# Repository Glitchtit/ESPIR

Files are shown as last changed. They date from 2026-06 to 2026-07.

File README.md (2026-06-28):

# ESPIR — Zigbee IR Blaster for Home Assistant

A Home Assistant–controlled IR blaster built on the **ESP32-C6**, connected over
**Zigbee** to a **Zigbee2MQTT (Z2M)** coordinator. It **learns** IR codes from your
existing physical remotes and **replays** them on command, so HA buttons map 1:1 to
"press button → appliance fires the learned signal."

## Topology

```
[remote] --IR--> [VS1838B] --RMT RX--> MASTER (DevKitC-1, USB, Zigbee Router)
                                          |  NVS slots, custom ZCL cluster 0xFC00
                                          |  +--RMT TX--> [SZHJW] --IR--> appliance
                                          v
                       Zigbee <--> Z2M (z2m/espir.js) <--> Home Assistant
                                          |                       |
                              learn / send / read code     buttons + scripts
                                          v
        replication (HA script): copy master's learned code -> each SLAVE
                                          v
                       SLAVE (XIAO C6, LiPo, Sleepy End Device) --IR--> local appliance
```

- **Master** (ESP32-C6-DevKitC-1, USB-powered Zigbee **Router**): **learns** by raw-capturing
  from a **VS1838B** receiver and **transmits** through an **SZHJW** dual-LED module — both on
  the RMT peripheral; stores codes in NVS. Always-on, so it responds instantly and extends the
  Zigbee mesh.
- **Slave** (Seeed XIAO ESP32-C6, LiPo **Sleepy End Device**): transmit-only repeater for
  coverage in another spot, using the SZHJW dual-LED emitter (RMT). Receives learned codes
  from the master via a replication path.

> **Protocol note:** raw capture learns essentially **any** remote; NEC is auto-compacted to
> `{address, command}` for cheap storage/replication. Master and slaves share the RMT backend,
> so codes are fully interoperable.

## Why this design

A battery IR blaster that must answer HA instantly is a contradiction — Zigbee on the C6
only sips power if it sleeps deeply. The master/slave split sidesteps it: the master is
mains/USB-powered (snappy, full range, does the learning); slaves are battery and only need
to fire eventually at their own nearby appliance.

## Repo layout

| Path | What |
|---|---|
| `components/espir_ir` | RMT IR transmit (software 38 kHz carrier) + raw receive |
| `components/espir_codec` | NEC decode/encode + raw↔compact helpers |
| `components/espir_store` | NVS slot store (save/load/clear, chunked program) |
| `components/espir_zcl` | Custom ZCL cluster `0xFC00` contract (`espir_proto.h`) |
| `components/espir_device`| Zigbee device: endpoint, cluster server, learn FSM (shared) |
| `components/espir_led` | RGB status LED (LEDC PWM) for the custom-PCB slave |
| `components/espir_oled`  | 0.91″ SSD1306 128×32 I²C status display for the master |
| `master/` | ESP-IDF app: VS1838B learn + SZHJW transmit (Router) |
| `slave/` | ESP-IDF app: SZHJW transmit + program/send (Sleepy End Device) |
| `slave-pcb/` | Custom-PCB slave firmware: discrete MOSFET IR driver + RGB status LED (XIAO-carrier pinout) |
| `z2m/espir.js` | Zigbee2MQTT external converter (mirrors the cluster contract) |
| `homeassistant/` | Replication script + example button entities |
| `hardware/` | BOM + wiring; incl. [`pcb-fully-custom.md`](hardware/pcb-fully-custom.md) — the fully-custom discrete-ESP32-C6 slave board |
| `docs/specs/` | Design spec |

## Wiring & pinout

Pins are defaults — override in `idf.py menuconfig → ESPIR Configuration`. All grounds must
be common. Full notes (caps, boost, battery sense) in
[`hardware/wiring-master.md`](hardware/wiring-master.md) and
[`hardware/wiring-slave.md`](hardware/wiring-slave.md).

### Master — ESP32-C6-DevKitC-1 (USB powered)

The master uses an **SZHJW** dual-LED module (RMT) for **transmitting** and a **VS1838B**
38 kHz receiver (RMT raw capture) for **learning** — both straight on the C6. Raw capture
learns **any** remote protocol; NEC is auto-compacted.

| Signal | C6 GPIO | Connects to |
|---|---|---|
| IR TX data | **GPIO6** | SZHJW `DAT` |
| IR RX data | **GPIO4** | VS1838B `OUT` |
| OLED I²C SDA | **GPIO22** | SSD1306 `SDA` |
| OLED I²C SCL | **GPIO23** | SSD1306 `SCK` (= SCL) |
| 5 V | `5V` pin | SZHJW `VCC` |
| 3.3 V | `3V3` pin | VS1838B `VCC` (**3.3 V only**) **and** SSD1306 `VCC` |
| GND | any `GND` | SZHJW `GND`, VS1838B `GND` **and** SSD1306 `GND` |

An optional **0.91″ SSD1306 128×32 I²C OLED** (addr 0x3C) shows the active slot, whether it
holds a code (`STORED`/`EMPTY`), and learn/connection state. Set `ESPIR_OLED_ENABLE=n` to omit
it — the firmware runs normally without a panel.

```
DevKitC-1                         SZHJW dual-LED TX (5 V) — SEND
  5V    ──────────────────────────► VCC
  GPIO6 ──────────────────────────► DAT
  GND ──────────────┬─────────────► GND
                    │
  3V3 ──────────────┼─────────────► VCC   VS1838B receiver (3.3 V ONLY) — LEARN
  GPIO4 ◄───────────┼────────────── OUT
  GND ──────────────┴─────────────► GND
```

Power the VS1838B at **3.3 V** (its `OUT` drives a GPIO directly). Avoid GPIO12/13
(USB-Serial-JTAG) and strapping pins GPIO8/9/15. (The YS-IRTM module is no longer used.)

### Slave — Seeed XIAO ESP32-C6 (LiPo powered, transmit-only)

No 5 V rail on battery, so the transmitter runs at battery voltage (~3.7–4.2 V → reduced
range). No receiver.

| Signal | XIAO pad | C6 GPIO | Connects to |
|---|---|---|---|
| IR TX data | **D2** | GPIO2 | SZHJW `DAT` |
| Power for IR TX | `BAT+` (or `5V` on USB) | — | SZHJW `VCC` |
| GND | `GND` | — | SZHJW `GND` |
| LiPo ± | `BAT+` / `BAT−` | — | 3.7 V LiPo cell (charges over USB-C) |

```
XIAO ESP32-C6                     SZHJW IR TX (2× 940nm emitters)
  BAT+ ──────────────────────────► VCC   (≈3.7–4.2 V; reduced range)
  D2 (GPIO2) ────────────────────► DAT
  GND ───────────────────────────► GND
  BAT+ / BAT− ◄──────────────────── 3.7 V LiPo cell
```

### Custom slave PCBs (permanent builds)

Two ways to turn the jumper-wire slave into a board:

1. **XIAO-carrier** — reflow a XIAO ESP32-C6 onto a small PCB + a discrete IR driver + RGB status
   LED. See [`hardware/wiring-slave.md` → Custom PCB](hardware/wiring-slave.md#custom-pcb-xiao-esp32-c6-as-an-smd-part).
2. **Fully custom (bare ESP32-C6)** — a complete standalone board: discrete C6 (QFN-40) with its own
   USB-C, MCP73831 LiPo charger, AP2112K LDO + load-share, chip antenna (+ u.FL), SPI flash and
   40 MHz crystal, the 2-LED IR driver, and an addressable RGB status LED. Verified to meet the
   slave requirements (Zigbee, battery+charging, USB-C flash/power). See
   [`hardware/pcb-fully-custom.md`](hardware/pcb-fully-custom.md). *(Hardware designed in EasyEDA
   Pro; it moves the IR pin to GPIO2 and the status LED to a single GPIO11 data line, so it needs a
   firmware variant — noted in that doc.)*

## Build & flash

Requires ESP-IDF v5.4+ (`. ~/esp/esp-idf/export.sh` to load the environment).
See [`AGENTS.md`](AGENTS.md) for the full command reference.

```sh
. ~/esp/esp-idf/export.sh

# Master (on the DevKitC-1)
cd master && idf.py set-target esp32c6 && idf.py build flash monitor

# Slave (on the XIAO C6)
cd slave  && idf.py set-target esp32c6 && idf.py build flash monitor

# Custom-PCB slave (XIAO C6 + discrete IR driver + RGB status LED)
cd slave-pcb && idf.py set-target esp32c6 && idf.py build flash monitor
```

## Pairing & usage

1. Drop `z2m/espir.js` into your Z2M `external_converters/` and restart Z2M.
2. Enable joining in Z2M; power on the device; it joins and appears with learn/send entities.
3. To learn: set the target slot, trigger **learn**, point the remote at the master's
   receiver, press the remote key. The captured code is stored in that slot.
4. Bind an HA button to **send slot N**. To cover another room, replicate the code to a
   slave (see `homeassistant/replicate-codes.yaml`).

The HA **Slot** selector drives the device over the `selectSlot` command (manufacturer-specific
ZCL attributes aren't OTA-writable on zboss). The device reports the active slot and whether it
holds a code back to HA (`slot_occupied`) and to the master OLED.

## Over-the-air updates

The master **and both slave builds** support Zigbee OTA firmware updates via Zigbee2MQTT.

**One-time migration:** the OTA-capable firmware uses a new dual-slot partition table,
so the first time you load it you must flash that device over USB (`cd <app> && idf.py flash`,
where `<app>` is `master`, `slave`, or `slave-pcb`). The device re-pairs to your Zigbee
network once after this flash. All later updates are wireless. (Slaves are sleepy end
devices, so their wireless transfers are slower — do them on good battery/USB power.)

**Point Z2M at the image index** — in your Zigbee2MQTT `configuration.yaml`:

    ota:
      zigbee_ota_override_index_location: https://raw.githubusercontent.com/Glitchtit/ESPIR/main/z2m/ota/index.json

Restart Z2M. Each ESPIR device then appears in the OTA tab. Click "Check", then "Update"
when a newer version is offered. The device downloads in the background, reboots into the
new firmware, and confirms it; a bad image rolls back automatically on next boot.

## Status

Firmware and host integration are written and **both apps build clean** for esp32c6
(ESP-IDF v5.4, esp-zigbee-lib 1.6.8):

- ✅ Shared components (`espir_ir` RMT TX/RX, `espir_codec` NEC+raw, `espir_store` NVS slots)
- ✅ Master app — Zigbee Router, custom cluster `0xFC00`, learn FSM
- ✅ Master OLED (`espir_oled`) — active slot, `STORED`/`EMPTY`, learn/connection state
- ✅ Slave app — Zigbee Sleepy End Device, transmit-only
- ✅ Z2M converter, HA replication script, hardware docs

**Verified on hardware:** the master pairs to Zigbee2MQTT, exposes the custom cluster,
status fields populate live in HA, learn/send work end-to-end over the RMT path, and the OLED
tracks the active slot + `STORED`/`EMPTY` occupancy live. Wire the
master per [`hardware/wiring-master.md`](hardware/wiring-master.md) (SZHJW on GPIO6, VS1838B on
GPIO4 at 3.3 V, SSD1306 on GPIO22/23). **Remaining:** flash/pair the XIAO **slave** and exercise
the replication path (`homeassistant/replicate-codes.yaml`).

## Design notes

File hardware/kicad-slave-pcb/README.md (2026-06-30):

# ESPIR slave PCB — KiCad

The KiCad realization of the ESPIR fully-custom slave board. The original is
captured in EasyEDA Pro (see [`../pcb-fully-custom.md`](../pcb-fully-custom.md));
that board file "lives in the EasyEDA workspace, not in git." This directory is
the same circuit rebuilt **in KiCad**, fully in-repo and reproducible from source.

Schematic (connect-by-name net labels), placement, and the autorouted board:

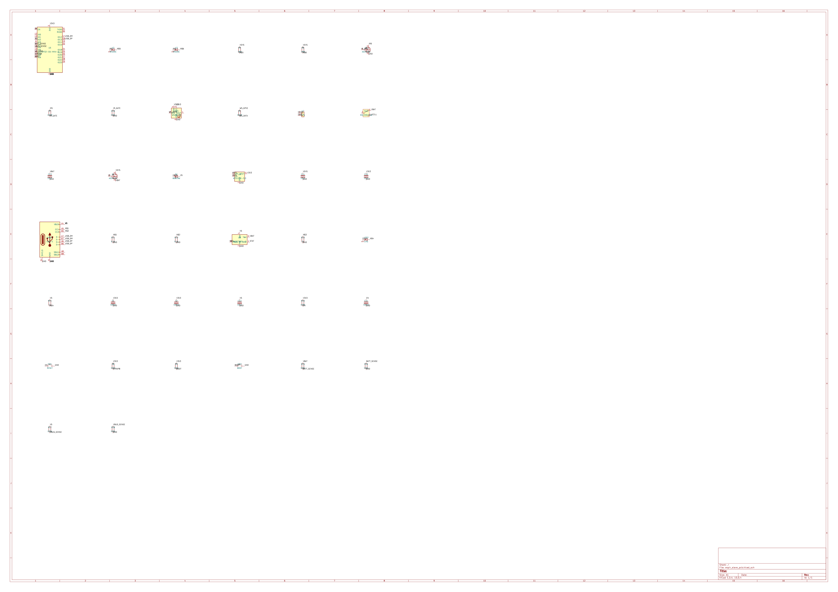
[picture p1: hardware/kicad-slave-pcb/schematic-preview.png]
schematic preview

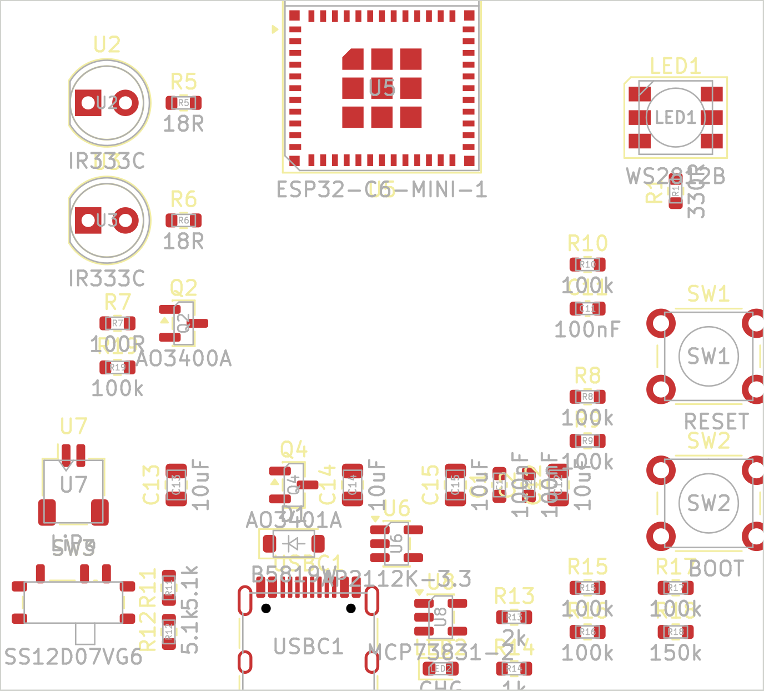
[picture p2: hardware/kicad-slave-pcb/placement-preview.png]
placement preview

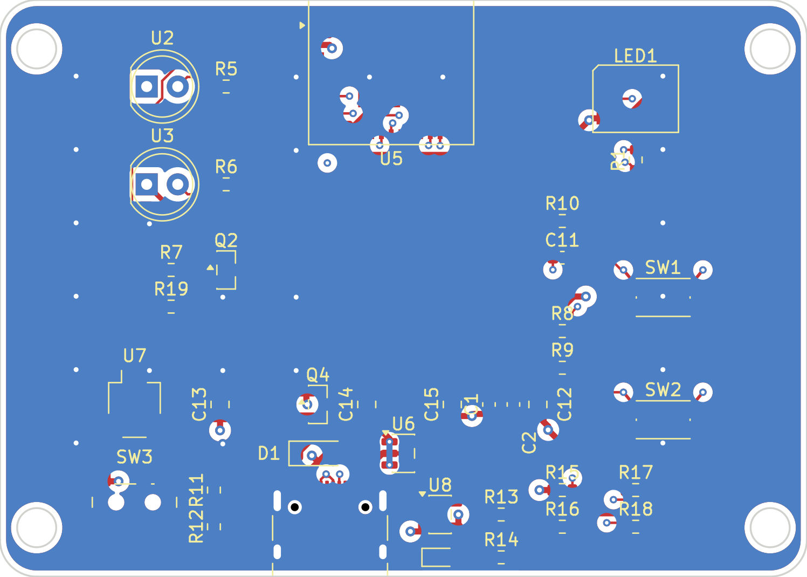
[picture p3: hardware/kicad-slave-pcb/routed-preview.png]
routed preview


## What this is

The circuit is described **as code** with [SKiDL](https://github.com/devbisme/skidl)
(`espir_slave_pcb.py`) — a Python netlist HDL that looks up real KiCad library
symbols and emits an authoritative KiCad netlist. From that one netlist:
`make_schematic.py` generates an openable **`.kicad_sch`** (every part + a net
label on each pin — connect-by-name), and `kinet2pcb` + a `pcbnew` script produce
the **`.kicad_pcb`** (footprints, nets, functional placement, board outline).

```
                    ┌─ make_schematic.py ─▶  espir_slave_pcb.kicad_sch  (schematic)
espir_slave_pcb.py ─┤  (+ SKiDL ERC)
   (the circuit)    └─ espir_slave_pcb.net ─ kinet2pcb ─▶ espir_slave_pcb.kicad_pcb ─ place_and_outline.py
```

| File | What |
|---|---|
| `espir_slave_pcb.py` | **The circuit** — SKiDL source (parts + nets). The schematic-of-record. |
| `espir_slave_pcb.net` | Generated KiCad netlist (authoritative connectivity). |
| `make_schematic.py` | netlist → `.kicad_sch` (real symbols embedded; connect-by-name labels). |
| `espir_slave_pcb.kicad_sch` | KiCad schematic: 38 components, 25 nets — connectivity is an **exact match** to the netlist. |
| `place_and_outline.py` | `pcbnew` pass: 4-layer setup + functional placement + Edge.Cuts + Power/IR net classes. |
| `route.sh` | Autoroute via Freerouting (DSN → SES). KiCad has no built-in headless autorouter. |
| `pour_gnd.py` | GND pours on all 4 layers + solid GND-pad connection + collision-checked via stitching. `planes-only` mode pours the planes without stitching (run before routing). |
| `fix_silk.py` | Collision-aware silkscreen designator placement; hides refs with no clear spot. |
| `en_jumper.py` | Jumpers the LDO EN→VIN tie on B.Cu (boxed pins Freerouting can't tie). |
| `mounting_and_round.py`  | Expand X (centred), round the corners (r=3 mm), add 4× M3 mounting holes. |
| `swap_smd_button.py` | Swap one button THT→SMD on the routed board (bridge signal, reconnect inner layers via a via, GND via pour). |
| `espir_slave_pcb.kicad_pcb` | **4-layer** KiCad board: 38 footprints, **fully routed**, 0.5 mm power incl. VBAT, GND planes, centred on A4. |
| `espir_slave_pcb.kicad_dru` | Critical-signal **routing rules** (power width, IR-pulse width, sense-vs-IR clearance, USB width) — DRC auto-enforces them. |
| `espir_slave_pcb.kicad_pro` | KiCad project (open this). |
| `build.sh` | Reproduces everything from source. |

> The schematic uses **connect-by-name net labels** (a label on every pin) rather
> than drawn wires — the standard scriptable way to express a netlist graphically.
> KiCad re-extracts the identical 25-net netlist from it (verified). Its ERC items
> (off-grid label endpoints, floating NC pins, power-pin-not-driven, lib-symbol
> cache mismatch) are cosmetic, not connectivity errors. Drawing wires / tidy
> placement is GUI finishing work.

## Adjustment vs the EasyEDA discrete-C6 board

Per request this build uses the **ESP32-C6-MINI-1 module** instead of the bare
ESP32-C6 QFN-40. The module integrates the SPI flash, 40 MHz crystal + load caps,
RF chip antenna + π-match, and the EP grounding — so the circuit **drops** those
discrete parts entirely:

| Dropped (now internal to the module) | Was in the discrete design |
|---|---|
| `U4` W25Q32 flash + decoupling | external SPI flash |
| `X1` 40 MHz crystal + `C9`/`C10` | external crystal + load caps |
| `AE1` chip antenna, `RF1` u.FL, `R2`/`R3`/`R4` π-match | external antenna chain |

Everything else carries over: USB-C + load-share + LiPo-charger power tree,
AP2112K 3V3 LDO, 2-LED discrete IR driver, addressable RGB status LED,
battery/VBUS sense dividers, reset/boot buttons, battery slide switch.

**GPIO remap:** the MINI-1 module does not bring out GPIO11, so the WS2812
status-LED data line moves **GPIO11 → GPIO7** (a free, non-strapping exposed pin).
All other pins are unchanged: IR on GPIO2, battery/VBUS sense on GPIO4/GPIO5,
USB on GPIO12/GPIO13, boot on GPIO9, strap pull-up on GPIO8.

> The `slave-pcb/` firmware would need the same one-line pin change
> (`WS_GPIO 11 → 7`) it already needs for this board family.

## Bill of materials (38 parts)

ESP32-C6-MINI-1 module · AP2112K-3.3 LDO · MCP73831 LiPo charger · AO3401A
load-share P-FET · B5819W (1N5819) OR-ing Schottky · AO3400A IR-driver N-FET ·
2× IR333C 940 nm IR LED · WS2812 RGB status LED · charge LED · USB-C (HRO
TYPE-C-31-M-12) · JST-SH LiPo connector · SS12D07VG6 slide switch · 2× SMD tactile (KMR2)
buttons · 17 resistors · 7 capacitors. Full values + LCSC numbers are in
[`../pcb-fully-custom.md`](../pcb-fully-custom.md).

## Build / reproduce

```bash
sudo pacman -S --needed kicad kicad-library kicad-library-3d  # -3d = component 3D models
python -m venv --system-site-packages .venv && . .venv/bin/activate
pip install skidl kinet2pcb
./build.sh
```

> Without `kicad-library-3d` the 3D viewer shows only bare pads on green FR4. The
> ESP32-C6-MINI-1 module has no stock 3D model (renders as pads even with it installed);
> add the vendor STEP and point U5's footprint `(model …)` at it if you want its body.

## Verification

- **ERC (SKiDL): 0 errors.** The 18 warnings are all *intentional* unconnected
  pins — the module's spare GPIOs (IO0/1/3/6/14/15/18–23, RXD0/TXD0), the USB-C
  SBU pins, the slide-switch OFF throw, and the WS2812 DOUT (no daisy-chain).
  Every wired pin lands on the right net.
- **Schematic (`kicad-cli sch export netlist`):** KiCad loads the generated
  `.kicad_sch` and re-extracts the **exact same 25 multi-pin nets** as the SKiDL
  netlist (verified set-equal). The schematic is a faithful graphical view of the
  circuit.
- **4-layer stackup** (F / In1 / In2 / B) with **GND pours on all four layers** + a
  collision-checked stitching-via grid — the inner copper acts as ground reference planes
  for stability. The extra routing room lets **every power rail, incl. VBAT, route at 0.5 mm**.
- **Pour order: GND planes are poured *before* routing** (`pour_gnd.py planes-only`), so the
  Specctra DSN exports GND as `(plane …)` per layer and Freerouting routes **only the signal
  nets** — no redundant GND traces, just the pad-to-plane vias GND needs. A full `pour_gnd.py`
  after routing re-fills around the new tracks and adds stitching.
- **Routing (`route.sh` → Freerouting, 4-layer):** **fully routed — 114/114** (310 tracks,
  43 vias incl. stitching). All `Power`-class rails are 0.5 mm. The LDO EN pin (tied to VSYS,
  boxed between U6's VIN/GND pins) is jumpered VIN→EN on B.Cu under the GND pin.
- **Module placement:** U5's body is at the **top edge so the antenna `tracks not_allowed`
  keep-out hangs OFF the board** — otherwise it covers the interior and the parts under it
  can't route.
- **Board centred** on the A4 drawing sheet (148.5, 105 mm).
- **Mechanical: 66 × 47 mm, rounded corners (r=3 mm), 4× M3 mounting holes** in the
  expanded left/right margins (clear of all components; GND pour isolates them).
- **DRC (`kicad-cli pcb drc`): 0 electrical violations** — 0 unconnected, 0 track-width,
  0 clearance, 0 copper-edge, 0 shorts. Remaining: **4 `silk_edge_clearance`** (U5 antenna +
  USB-C outlines overhanging their edges, by design — fab clips edge silk) and **1
  `lib_footprint_mismatch`** (U5 board copy vs the latest library version — same 61 pads,
  benign). LED2/USBC1 silk refs hidden (saturated cluster; still in BOM/CPL).

## Remaining work (the human finishing pass)

Same division of labour the EasyEDA workflow uses — the circuit + a clean,
function-grouped starting layout are done; the fab finishing is left to a human:

1. **Edge clearance for passives:** `place_and_outline.py` now enforces ≥1 mm board-edge
   clearance for every non-port/antenna part and places the USB-C CC pulldowns right at the
   connector. In the **committed board** the charge LED (LED2) + its ballast (R14) still sit
   ~0.8 mm from the bottom edge (within fab spec, but tight). Pushing them further means
   re-placing the dense USB-C/charger/divider cluster — a fresh `build.sh` regen applies the
   improved placement, but the bottom-center density leaves the **LDO EN tie + IR gate stub**
   for a short KiCad GUI routing session (interactive routing handles them trivially). The
   committed `.kicad_pcb` stays the verified-clean artifact.
2. **Optional polish:** trim U5/USB-C footprint silk that overhangs the edges (the 4 benign
   `silk_edge_clearance`), or leave it (fab clips it). For a true 90 Ω USB pair, rename
   `USB_DM`/`USB_DP` → `USB_D-`/`USB_D+`, set the stackup, Route → Differential Pair + Tune Skew.
2. ~~GND copper pours~~ — done (`pour_gnd.py`: all 4 layers + stitching vias).
3. Nudge silkscreen, confirm the **antenna keep-out** is clear of copper and the
   module antenna overhangs the top edge, verify **edge connectors** (USB-C bottom,
   JST left, buttons right) sit flush at their edges.
4. Set net-class track widths (Power/IR already declared in the project) and
   export Gerber/BOM/CPL.

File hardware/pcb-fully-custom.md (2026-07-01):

# Fully-custom slave PCB — discrete ESP32-C6 (Board2 / "PCB2")

The most integrated slave build: a **fully custom board around a bare ESP32-C6 (QFN-40)** — no
XIAO module. It folds everything the [XIAO-carrier custom PCB](wiring-slave.md#custom-pcb-xiao-esp32-c6-as-an-smd-part)
got from the module (USB-C, LiPo charging, antenna, 3.3 V regulation, flash, crystal) onto the
board itself, plus the 2-LED IR driver and an addressable RGB status LED.

> **Design intent:** a drop-in functional replacement for the *XIAO-ESP32-C6 + 2-diode IR sender*
> prototype — same SoC family, same IR-sender behaviour, **Zigbee** (the C6's native 802.15.4
> radio), **battery powered with charging**, and **USB-C** for flashing / connection / alt power /
> charging. (See the verification at the bottom.)

Designed in **EasyEDA Pro** (4-layer: Sig / GND / GND / Sig, chip-antenna keep-out, GND pours
stitched). Board file lives in the project's EasyEDA workspace, not in git.

> ⚠️ **Firmware status:** the `slave-pcb/` firmware currently targets the **XIAO-carrier** pinout
> (IR on GPIO18, a 3-channel LEDC common-anode RGB on GPIO17/19/20, battery sense on GPIO0). This
> board moves things (IR → **GPIO2**, status LED → a single **GPIO11** addressable-LED data line,
> sense on **GPIO4/GPIO5**) and flashes over **native USB**. So this board needs a firmware
> variant: remap the IR pin, **swap the 3-channel RGB driver for a WS2812-style single-wire driver**,
> and point battery/VBUS sense at GPIO4/GPIO5. The hardware is done; that firmware delta is the
> open work item.

## Block diagram

```
                USB-C (USBC1)  ──VBUS(5V)──┬────────────────┐
                  │  D+/D- (CC1/CC2 5.1k pulldowns)          │
                  │   │                                      ▼
                  │   │                              MCP73831 charger (U8) ──VBAT──► battery (U7, SH-MX1.25)
                  │   │                                      │                         │
                  │   │                                      └── STAT → LED2           SW3 (slide on/off)
                  │   │                                                                 │
   V5 ──D1(Schottky)──┐                                          VBAT ──────────────────┘
                      ▼                                            │
   VBAT ─Q4(P-FET load-share, gate=V5)─► VSYS ─► AP2112K LDO (U6) ─► 3V3 ─► ESP32-C6 (U5) + flash (U4)
                                                                              │
   ESP32-C6 (U5, QFN-40) ── SPI ──► W25Q32 flash (U4)                         │
        │  XTAL_P/N ── 40 MHz crystal (X1) + load caps                        │
        │  ANT ──R2──► π-match ──R3──► chip antenna (AE1)   (R4──► u.FL RF1)   │
        │  GPIO12/13 ◄── USB D-/D-                                            (decoupling C1..C8)
        │  GPIO2 ──► Q2 gate ──► 2× IR LED (U2,U3 parallel, VSYS via R5/R6) ──► GND
        │  GPIO11 ──R1──► WS2812-style RGB status LED (LED1)
        │  GPIO4 ◄── battery divider (R15/R16)     GPIO5 ◄── VBUS divider (R17/R18)
        │  EN ◄── reset (SW1)   GPIO9 ◄── boot (SW2)
```

## U5 GPIO map (verified from the schematic netlist)

| ESP32-C6 pin | Net | Function |
|---|---|---|
| **GPIO2** | `IR1` | IR drive → Q2 gate (both IR LEDs) |
| **GPIO11** | `WS_GPIO` | Addressable RGB status LED data (→ R1 → LED1.DIN) |
| **GPIO12 / GPIO13** | `USB_DM` / `USB_DP` | Native USB Serial/JTAG → USB-C (firmware upload) |
| **GPIO4** (MTMS) | `BATT_SENSE` | Battery-voltage divider (ADC1) |
| **GPIO5** (MTDI) | `VBUS_SENSE` | USB-present divider (ADC1) |
| **GPIO9** | strap | Boot button (SW2) + pull-up; download mode |
| **GPIO8** | strap | Boot strap + pull-up |
| **EN** (CHIP_PU) | `EN` | Reset button (SW1) + R10 pull-up + C11 |
| **XTAL_P / XTAL_N** | `XIN` / `XOUT` | 40 MHz crystal X1 + load caps C9/C10 |
| **SPICLK/SPICS0/SPID/SPIQ/SPIWP/SPIHD** | SPI | External flash U4 (W25Q32) |
| `ANT` | `ANTRF` | RF feed → R2 → π-match |

> GPIO3 (`IR2`) and GPIO10 (`IR3`) are leftover single-pin nets from an earlier 3-channel IR draft —
> unused on this board (the IR sender is **2 LEDs on one FET**, driven by GPIO2 only). Free for future use.
>
> Battery/VBUS sense sit on **GPIO4/GPIO5 = the JTAG MTMS/MTDI pins** — fine as ADC1 inputs, at the
> cost of hardware-JTAG debug (USB Serial/JTAG still works for flashing/console).

## Bill of materials (verified LCSC parts; passive values per schematic)

**Core / actives**

| Ref | Part | LCSC | Notes |
|-----|---|---|---|
| U5 | **ESP32-C6** (bare, QFN-40-EP) | `C5364646` | the SoC; needs ext. flash + 40 MHz crystal; ≥9 GND vias in the EPAD |
| U4 | **W25Q32** SPI flash, SOIC-8 | `C82317` | bare C6 has the SPI-flash bus bonded out |
| U6 | **AP2112K-3.3** LDO, SOT-23-5 | `C51118` | VSYS → 3.3 V (low-dropout — works from a ~3.4 V cell; AMS1117 can't) |
| U8 | **MCP73831** LiPo charger, SOT-23-5 | `C42432883` | VBUS → VBAT single-cell charge; STAT → LED2; PROG sets current |
| X1 | **40 MHz** crystal | `C5210647` | required by the C6 |
| Q4 | **AO3401A** P-MOSFET, SOT-23 | `C15127` | load-share (battery → VSYS, gate = V5) |
| D1 | **B5819W** Schottky | `C8598` | USB 5 V → VSYS (load-share OR-ing) |
| Q2 | **AO3400A** N-MOSFET, SOT-23 | `C20917` | low-side IR LED driver (both LEDs) |
| U2, U3 | **IR333C** 5 mm 940 nm IR LED (THT) | `C5200795` | ×2, in parallel — each via its own ballast (R5/R6) |
| LED1 | **WS2812-style addressable RGB** (TCWIN, SMD) | `C48982517` | single-wire status LED on GPIO11 (1=DO,2=GND,3=DIN,4=VDD) |
| LED2 | charge-status LED (SMD) | — | MCP73831 `STAT` indicator |

**Connectors / switches**

| Ref | Part | LCSC | Notes |
|-----|---|---|---|
| USBC1 | **USB-C** receptacle, 16P | `C165948` | data (D±) + VBUS + CC; flashing, power, charging |
| U7 | **SH-MX1.25-2PWT** battery connector (1.25 mm 2P) | `C53477378` | LiPo cell; verify polarity before first plug-in |
| RF1 | **u.FL / IPEX** RF connector | `C434808` | external-antenna option |
| AE1 | **Johanson 2450AT18A100E** 2.4 GHz chip antenna | `C89334` | on-board antenna (needs copper keep-out) |
| SW1 | tactile button (TS-1187A) | `C318884` | **reset** (EN) |
| SW2 | tactile button (TS-1187A) | `C318884` | **boot** (GPIO9, download mode) |
| SW3 | **SS12D07VG6** SPDT slide switch | `C2939728` | battery on/off (in the VBAT line) |

**Passives (by function — confirm exact values against the schematic / EasyEDA BOM export)**

| Refs | Function | Typical |
|---|---|---|
| R5, R6 | IR-LED ballast (VSYS → anode), one per LED | ~18 Ω (see [sizing](wiring-slave.md#build-notes)) |
| R1 | WS2812 data series | ~330 Ω |
| R2 / R3 / R4 | RF feed / π-match / antenna-select (chip vs u.FL) | 0 Ω select — **populate R3 *xor* R4** |
| R10 | EN pull-up | 100 kΩ |
| R8, R9 | GPIO9 / GPIO8 strap pull-ups | 100 kΩ |
| R11, R12 | USB-C CC1/CC2 pulldowns | 5.1 kΩ |
| R13 | charger PROG (sets charge current) | e.g. 2 kΩ ≈ 500 mA |
| R14 | charge-status LED ballast | per LED |
| R15, R16 | battery divider → GPIO4 | per `ESPIR_BATTERY_DIV_X100` |
| R17, R18 | VBUS divider → GPIO5 | ~100 k / 150 k |
| C1–C8 | V3V3 decoupling (one per C6 power pin) | 100 nF |
| C9, C10 | crystal load caps | ~10 pF (per crystal CL) |
| C11 | EN cap | 100 nF–1 µF |
| C12 / C13 / C14 / C15 | V5 bulk / VBAT / VSYS / V3V3 reservoirs | 1–10 µF |

> The authoritative, value-complete BOM is the **EasyEDA `Export → Bill of Materials`** for PCB2 —
> regenerate it at order time (live LCSC stock changes daily).

## Power architecture

- **USB present:** VBUS(5 V) → D1 (Schottky) → VSYS, *and* → MCP73831 charges the LiPo. Q4 (P-FET,
  gate tied to V5) is **off** with USB present, so the battery doesn't back-feed VSYS.
- **On battery:** V5 = 0 → Q4 turns **on** → VBAT → VSYS. SW3 is the battery disconnect (storage
  off; charging only happens with SW3 on, since charge current flows through it).
- **Regulation:** VSYS → AP2112K LDO → 3.3 V for the C6 + flash. (Low-dropout so it still regulates
  near end-of-charge ~3.4 V.)
- **Telemetry:** battery divider → GPIO4, VBUS-present divider → GPIO5 (both ADC1).

## RF / Zigbee

ESP32-C6 has a native **IEEE 802.15.4** radio → Zigbee/Thread. Feed: `U5.ANT → R2 → ANTFEED`,
then **R3 → AE1** (Johanson chip antenna) **or R4 → RF1** (u.FL). **Populate only one of R3/R4.**
The chip antenna needs a copper keep-out (no pour/plane under or beside it) on all layers — done on
the layout. 40 MHz crystal X1 is mandatory.

## IR sender (matches the 2-diode prototype)

Two 940 nm IR LEDs (U2, U3) in **parallel**, each with its own ballast (R5/R6) from VSYS, cathodes
tied to **Q2** (AO3400A low-side N-FET) drain; **GPIO2** drives the gate. One signal fires both —
the same topology as the original XIAO 2-diode sender. Ballast/range sizing carries over from
[wiring-slave.md → Build notes](wiring-slave.md#build-notes).

## Requirements check (BOM + netlist verified)

| Requirement | Met? | Evidence |
|---|---|---|
| Drop-in replacement for XIAO-C6 + 2-diode IR sender | ✅ (functional) | U5 = ESP32-C6; `IRD1 = U2.C, U3.C, Q2.D` (both LED cathodes + FET drain), gate `IR1 = U5.GPIO2` — 2 LEDs on one FET. *(Functional, not the XIAO footprint.)* |
| Zigbee | ✅ | ESP32-C6 802.15.4 radio; `ANTRF→R2→R3→AE1` (u.FL alt via R4); 40 MHz X1 present |
| Battery + charging | ✅ | U7 battery, U8 MCP73831 charger, Q4/D1 load-share, U6 LDO, SW3 disconnect, R15/16 sense |
| USB-C connect / flash / alt-power / charge | ✅ | `USB_DM→GPIO12`, `USB_DP→GPIO13` (native USB Serial/JTAG); VBUS → charger + load-share; CC 5.1 k pulldowns |

**Open items:** firmware variant for this pinout (IR GPIO2, WS2812 RGB on GPIO11, sense GPIO4/5,
USB-native flashing); populate one antenna (R3 *xor* R4); the human finishing pass on the layout
(minor nudging, pour touch-ups, EP via array — see below).

## Notes from layout

- **EP grounding:** the QFN exposed pad must tie to GND with a **via array in the pad** (Espressif
  spec ≥9 ground vias in the C6 EPAD), small (~0.3 mm) and plugged/tented to avoid reflow
  solder-wicking — done on the footprint, not just a single stitching via.
- 4-layer stack with inner GND; chip-antenna copper keep-out before pouring; net-class widths for
  power/IR/RF; auto-routed then hand-finished.

## Flashing (sleepy end device — mind the wake window)

Flashing is over the bare C6's **native USB-Serial-JTAG** (`USB_DM→GPIO12`, `USB_DP→GPIO13` to
USB-C) — no UART bridge. As a Zigbee **sleepy end device** the serial only answers for a brief
window right after a reset, so a plain `idf.py flash` usually fails with `OSError: [Errno 71]
Protocol error` (esptool toggling RTS on the CDC-ACM link and/or the chip asleep); `--before`
tweaks don't help.

Reliable method — loop `write_flash` and reset the board so an attempt lands in the wake window.
From the app's `build` dir:

```sh
. ~/esp/esp-idf/export.sh
while true; do
  python -m esptool --chip esp32c6 -p /dev/ttyACM0 -b 460800 \
    --before default_reset --after hard_reset --connect-attempts 1 \
    write_flash @flash_args && break
  sleep 0.3
done
```

Holding **BOOT** while tapping **RESET** forces ROM download mode = unlimited window. This wired
flash is a one-time step onto the OTA dual-slot layout; afterwards updates go wireless via Zigbee
OTA (`AGENTS.md` → *OTA release*).

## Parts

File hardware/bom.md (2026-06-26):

# Bill of Materials

## Master unit

| Qty | Part | Notes |
|-----|---|---|
| 1 | ESP32-C6-DevKitC-1 (or clone, 4 MB+ flash) | USB-powered; provides 5 V rail |
| 1 | **SZHJW** dual-LED IR transmitter (5 V, `DAT/VCC/GND`) | **transmitting** (RMT, software 38 kHz carrier) |
| 1 | **VS1838B** / TSOP38238 38 kHz receiver | **learning** (RMT raw capture); power at 3.3 V |
| 1 | 0.91" SSD1306 OLED, 128×32, I²C (`GND/VCC/SCK/SDA`) | status display: live selected slot + learn state; power at 3.3 V, I²C addr 0x3C |
| — | jumper wires | — |

Master = SZHJW (send) + VS1838B (learn), both on the C6 RMT peripheral. Raw capture learns
**any** remote protocol; NEC is auto-compacted. (The YS-IRTM module is no longer used.)

## Slave unit (per extra coverage point)

| Qty | Part | Notes |
|-----|---|---|
| 1 | Seeed XIAO ESP32-C6 | onboard LiPo charging + battery pads |
| 1 | SZHJW dual-LED IR transmitter module | 5 V, `DAT/VCC/GND`, 940 nm, no internal carrier; runs at battery voltage (reduced range) — **breadboard/jumper-wire build** |
| 1 | 3.7 V LiPo cell | JST 1.25 mm (MX1.25) 2P plug; breadboard build solders the leads to the XIAO `BAT+`/`BAT−` pads (mind polarity) |
| 1 | (optional) 3.3 V→5 V boost converter | only if slave IR range proves insufficient |

The slave transmits with the SZHJW emitter driven by the C6's RMT peripheral (software
38 kHz carrier). It replays the codes the master learned.

### Custom-PCB build (discrete IR driver)

Replaces the SZHJW module with a discrete driver so the LEDs run **straight off GPIO18** (no
module). See `hardware/wiring-slave.md` → *Custom PCB* for the schematic and sizing.

> **Two custom-PCB options.** The build below reflows a **XIAO module** onto a carrier (quickest
> path to a permanent slave). For a **fully integrated, fully custom board around a bare
> ESP32-C6** — its own USB-C, LiPo charger, antenna, 3.3 V LDO, flash and crystal, with the 2-LED
> IR driver and an addressable RGB status LED — see [`pcb-fully-custom.md`](pcb-fully-custom.md)
> (the discrete-C6 board designed in EasyEDA Pro; includes its own verified BOM).

LCSC/JLCPCB part numbers are listed where confirmed; passives marked **Basic** are standard JLC
Basic values — let the JLCPCB BOM tool match the C-number (no part fee). Live stock changes daily,
so confirm quantities at checkout.

| Qty | Part | LCSC | Notes |
|-----|---|---|---|
| 1 | Seeed XIAO ESP32-C6 | C9900124963 | reflowed on castellations; JLC Assembly (hand-place / module) |
| 1 | AO3400A N-MOSFET (SOT-23) | C20917 | IR driver, logic-level low-side switch (Basic) |
| 2 | 940 nm IR LED — M3030E1IRS6G45-940 | *confirm on LCSC* | TCWIN; in parallel, each via its own 18 Ω ballast |
| 3 | 2N7002 N-MOSFET (SOT-23) | C8545 | RGB colour low-side switches (Basic) |
| 1 | RGB LED, **common-anode** — Everlight 22-23C/R6GHBHW-C01/2C | C181865 | status: amber=searching, green=joined, blue=sending; anode → `VBAT`; Vf R 1.85 / G,B 2.9 V, 5 mA |
| 1 | JST 1.25 mm (MX1.25) 2P header — ZX-MX1.25-2PWT | C7430468 | LiPo connector; match the cell's plug, verify polarity vs `BAT+` (or your SHOU HAN `SH-MX1.25-2PWT`) |
| 1 | SPDT slide switch, SMD — SS12D07VG6 | C2939728 | on/off; in series in the `BAT+` line (battery disconnect) |
| 2 | 18 Ω ¼ W resistor | Basic | IR ballast, one per IR LED |
| 1 | 470 Ω resistor | Basic | red LED ballast (R_r) |
| 2 | 220 Ω resistor | Basic | green/blue LED ballast (R_g/R_b) |
| 1 | 100 Ω resistor | Basic | IR gate series |
| 1 | 100 kΩ resistor | Basic | IR gate pulldown |
| 2 | 56.9 kΩ 1 % resistor | Basic | battery divider → GPIO0 (`CONFIG_ESPIR_BATTERY_DIV_X100 = 200`; 56 kΩ also fine) |
| 2 | 100 kΩ + 150 kΩ resistor | Basic | VBUS-sense divider → GPIO1 |
| 2 | 100 µF cap (≥6.3 V) | Basic | `VBAT` reservoir for the IR pulse bursts |
| 1 | 100 nF cap (0603 X7R) | C14663 | decoupling (C3), placed at the XIAO `5V`/`3V3` pin (Basic) |

The RGB status LED is driven by the dedicated `slave-pcb/` firmware (LEDC PWM on three GPIOs). Each
colour is switched low-side by a 2N7002 with the LED's common anode on `VBAT`, because the green/blue
dice (`Vf` ≈ 2.9 V) won't light reliably from a 3.3 V pin. The FETs keep the drive active-high, so
`CONFIG_ESPIR_LED_COMMON_ANODE` stays **n**. The solid green only lights while USB is present so it
can't drain the LiPo; omit the VBUS divider (set `ESPIR_LED_VBUS_GPIO = -1`) to disable that gating.
Optional: 3× 100 kΩ gate→GND pulldowns on the RGB FETs kill boot-flicker.

## Notes

- **Power the VS1838B at 3.3 V** (master) — its `OUT` drives a GPIO directly; never 5 V.
- The SZHJW has its own transistor driver; the 3.3 V GPIO drives `DAT` fine. Run `VCC` at 5 V
  (master) for full range; at battery voltage on the slave (reduced range).
- A `~38–100 µF` cap across the SZHJW `VCC`/`GND` helps the LED current bursts.

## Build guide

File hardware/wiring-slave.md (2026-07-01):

# Wiring — Slave (Seeed XIAO ESP32-C6)

Battery-powered (LiPo on the BAT pads, charges over USB-C). Transmit-only — no receiver.
There is **no 5 V rail on battery**, so the IR transmitter runs at battery voltage
(~3.7–4.2 V), which reduces range. Add a boost converter only if needed.

## Pin assignments (defaults — override in `menuconfig` → ESPIR Configuration)

| Signal | XIAO pad | C6 GPIO | Connects to |
|---|---|---|---|
| IR TX data | **D10** | GPIO18 | SZHJW `DAT` |
| Power for IR TX | `BAT+` (battery) or `3V3`/`5V` (USB) | — | SZHJW `VCC` |
| GND | `GND` | — | SZHJW `GND` |
| **Battery sense** | **A0 / D0** | GPIO0 | divider mid-point (see below) |
| LiPo + | `BAT+` | — | battery + |
| LiPo − | `BAT−` | — | battery − |

```
XIAO ESP32-C6                     SZHJW IR TX (2× 940nm)
  BAT+ ──────────────────────────► VCC   (≈3.7–4.2V on battery; reduced range)
  D10 (GPIO18) ──────────────────► DAT
  GND ───────────────────────────► GND

  BAT+ / BAT− ◄──────────────────  3.7V LiPo cell
  USB-C ............................ charges the LiPo, also powers the unit when plugged

Battery sense (1:2 divider — required for the battery indicator):

  BAT+ ──[ R_top 55kΩ ]──┬──► D0 (= A0 = GPIO0)
                         │
                      [ R_bottom 55kΩ ]
                         │
                        GND
```

> On the XIAO ESP32-C6 the pin is silkscreened **D0** — it is the same pin as **A0 / GPIO0**.

## Battery indicator

The firmware reads `A0`/GPIO0, undoes the divider, maps 3.30 V→0 % … 4.20 V→100 %, and reports
**battery %** and **voltage** over the standard Zigbee Power Configuration cluster (0x0001)
every ~10 minutes. Z2M then shows a battery entity (the `ESPIR-SLAVE` converter exposes
`battery` + `battery_voltage`).

- **Recommended: two 55 kΩ** (a 1:2 divider → the default ÷2). Low impedance (~27 kΩ Thévenin),
  so the ESP32 ADC reads it accurately with **no cap needed**. Idle drain ~38 µA — negligible
  for a LiPo. This is what works reliably in practice on GPIO0.
- **Avoid 1 MΩ:1 MΩ here.** Tested on hardware it under-reads even with a 100 nF cap: a 4.0 V
  cell gave 1.68 V at D0 instead of 2.0 V. The pin's tiny DC leakage current loads a divider
  that stiff, dragging the node down; the cap only fixes AC settling, not the DC droop. Keep the
  divider impedance low (tens of kΩ).
- **Different/unequal resistors?** Set the ratio in `menuconfig` → ESPIR Configuration →
  *Battery divider ratio ×100* (`CONFIG_ESPIR_BATTERY_DIV_X100`):
  `(R_top + R_bottom) * 100 / R_bottom`. Example: 55 kΩ:55 kΩ → **200**. Put the *larger*
  resistor on top and keep the divided voltage under ~2.5 V at 4.2 V full so the ADC doesn't clip.
- The ADC pin is `CONFIG_ESPIR_BATTERY_ADC_GPIO` (default 0 = A0); must be an ADC1 pin (GPIO0–6).

## Notes

- A 38–100 µF cap across the SZHJW `VCC`/`GND` is more important here than on the master —
  the LED pulses sag a small LiPo.
- If range is too short for the slave's appliance, add a 3.3 V→5 V boost feeding the SZHJW
  `VCC` (the GPIO still drives `DAT` at 3.3 V — fine for the module's transistor).
- Sleepy End Device: sleep is join-safe and enabled (`CONFIG_PM_ENABLE`). Commands/sends are
  delivered on the next parent poll, so a held send fires a fraction of a second after the master.
- XIAO antenna: GPIO3/GPIO14 select the onboard vs external antenna (handled in firmware;
  see `CONFIG_ESPIR_XIAO_EXT_ANTENNA`). Onboard is the default.

## Custom PCB (XIAO ESP32-C6 as an SMD part)

For a permanent slave you can drop the jumper wires and the SZHJW module entirely: reflow the
XIAO onto a small carrier PCB and build the IR transmitter from discrete parts driven **straight
from GPIO18**. A logic-level N-MOSFET switches two 940 nm LEDs; the SZHJW's internal transistor
is just moved onto your board. The IR/battery **pins are unchanged** — GPIO18 still emits the
38 kHz `DAT` envelope (now into the MOSFET gate), GPIO0 still reads the battery divider. The board
also adds a discrete RGB status LED (see below), so it has its own firmware target, **`slave-pcb/`**
— identical to `slave/` plus the LED. Everything else matches
[the module section above](#pin-assignments-defaults--override-in-menuconfig--espir-configuration).

### Components

| Ref | Part | Value / notes |
|-----|---|---|
| U1 | Seeed XIAO ESP32-C6 (LCSC `C9900124963`) | reflowed on castellations; supplies `BAT+`, `GND`, drives GPIO18/GPIO0 |
| Q1 | **AO3400A** N-MOSFET, SOT-23 (LCSC `C20917`) | logic-level: Vgs(th) ≤ ~1.5 V, Id ≥ 0.5 A, low Rds(on) @ Vgs = 3.3 V (SI2302 / DMN2075U equiv.) |
| U2, U3 | 940 nm IR LED — M3030E1IRS6G45-940 (`Vf` 1.4–2.0 V @ 350 mA, `If` 350 mA) | TCWIN; in parallel, each via its own ballast — confirm the C# on its LCSC page |
| R1, R2 | Ballast resistor | **18 Ω, ≥ ¼ W** (1206 or axial) — one per LED |
| R3 | Gate series resistor | **100 Ω** (0603) — tames the gate edge into GPIO18 |
| R4 | Gate pulldown | **100 kΩ** (0603) — holds Q1 off while GPIO18 is hi-Z |
| R5, R6 | Battery divider | **2× 56.9 kΩ** (or 56 kΩ), 1 % — `CONFIG_ESPIR_BATTERY_DIV_X100 = 200` |
| C1, C2 | Reservoir caps | **100 µF** low-ESR (47–220 µF, MLCC/tantalum) at the LED anodes |
| C3 | Decoupling — 100 nF 0603 X7R (LCSC `C14663`) | across `VBAT`/GND, at the XIAO power pin |
| CN1 | JST 1.25 mm (MX1.25) 2P header — ZX-MX1.25-2PWT (LCSC `C7430468`) | LiPo connector to the XIAO `BAT+`/`BAT−` pads — **match the cell's plug & verify polarity** |
| SW1 | SPDT slide switch, SMD — SS12D07VG6 (LCSC `C2939728`) | on/off: in series in the `BAT+` line (common + one throw) — see *Build notes* |

### Connections

Only four signals leave the XIAO; `3V3` is not needed and GPIO3/GPIO14 antenna-select stay
on-module.

| XIAO pad | Net | Goes to |
|---|-----|---|
| `BAT+` | `VBAT` | R1/R2 (LED anodes), C1/C2 +, C3 +, R5 (divider) — fed via SW1 from CN1 |
| `D10` (GPIO18) | `IR_DRIVE` | R3 → Q1 gate (R4 gate→GND) |
| `A0`/`D0` (GPIO0) | `BATT_SENSE` | divider mid-point (R5 / R6) |
| `GND` | `GND` | Q1 source, C1/C2 −, C3 −, R6, LED return (via Q1 drain) |

```
 CN1 (cell +) ──[ SW1 on/off ]──● VBAT  (= XIAO BAT+ pad)

 VBAT ─┬──[ R1 18Ω ]──▶|─ U2 ─┐
       ├──[ R2 18Ω ]──▶|─ U3 ─┴─► Q1 drain   (Q1 = AO3400 low-side N-MOSFET;
       │                                         source → GND, gate ← R3)
       ├──[ C1 100µF ]── GND
       ├──[ C2 100µF ]── GND
       ├──[ C3 100nF ]── GND      ← decoupling, place at the XIAO power pin
       │
       └──[ R5 56.9kΩ ]──┬──► A0/GPIO0 (batt sense)
                         │
                     [ R6 56.9kΩ ]
                         │
                        GND

 D10/GPIO18 ──[ R3 100Ω ]──┬──► Q1 gate
                           │
                       [ R4 100kΩ ]
                           │
                          GND
```

### Status RGB LED

The `slave-pcb/` firmware drives an RGB LED (LEDC PWM on three GPIOs) to show device state:

| State | LED |
|---|-----|
| Searching for the Zigbee network | amber, slow blink |
| Joined / connected, idle | green, solid — **only while USB-powered** |
| Sending an IR frame | blue, rapid blink |
| On battery, idle | off (green suppressed — see below) |

**Why green is USB-gated:** a steady LED draws a few mA — ~100× the sleepy-ED idle budget — so on
battery the persistent green is suppressed to keep the months-long battery life. The amber-search
and blue-send blinks still run on battery (the CPU is already awake while commissioning or sending).
USB presence is read on a VBUS-sense GPIO; omit that divider (or set `ESPIR_LED_VBUS_GPIO = -1`) to
force the LED always-on at the cost of battery life.

**Driven from `VBAT`, not the 3.3 V GPIO.** Green/blue LED dice have `Vf ≈ 2.9 V` (and up to ~3.4 V
across RGB parts) — at or near a 3.3 V pin, so direct drive leaves them dark or barely lit. Instead each colour is switched
low-side by a small N-MOSFET with the LED's common anode on `VBAT` (~4 V), which gives real
headroom. The MOSFETs keep the firmware **active-high** (GPIO high → FET on → colour on), so
`CONFIG_ESPIR_LED_COMMON_ANODE` stays **n** even though the LED package is common-anode.

| Ref | Part | Value / notes |
|-----|---|---|
| LED1 | RGB LED, **common-anode** — Everlight 22-23C/R6GHBHW-C01/2C (LCSC `C181865`) | anode → `VBAT`; Vf R 1.85 / G,B 2.9 V, 5 mA; verify the colour-cathode pad order |
| Q2, Q3, Q4 | N-MOSFET, SOT-23 — 2N7002 (LCSC `C8545`) | low-side switch, one per colour (R/G/B); gate ← D7/D8/D9 |
| R7 | Red ballast | **470 Ω** — `(4.0−1.85)/470 ≈ 4.6 mA` |
| R8, R9 | Green/blue ballast | **220 Ω** — `(4.0−2.9)/220 ≈ 5.0 mA` (≈ the LED's 5 mA nominal) |
| R10, R11 | VBUS-sense divider | **100 kΩ** (top, from `5V`) : **150 kΩ** (bottom) → ~3.0 V |

Connections (defaults — `menuconfig` → ESPIR Configuration → *RGB status LED*):

| XIAO pad | C6 GPIO | Net | Goes to |
|---|---|-----|---|
| D7 | GPIO17 | LED_R | Q2 gate (drain → R7 → LED1 red cathode) |
| D8 | GPIO19 | LED_G | Q3 gate (drain → R8 → LED1 green cathode) |
| D9 | GPIO20 | LED_B | Q4 gate (drain → R9 → LED1 blue cathode) |
| D1 | GPIO1 | VBUS_SENSE | divider mid-point (`5V` ÷ ~1.67) |
| `BAT+` | — | VBAT | LED1 common anode |
| `GND` | — | GND | Q2/Q3/Q4 sources |

```
  XIAO 5V ──[ R10 100kΩ ]──┬──► D1/GPIO1   (USB present → HIGH; 0 V on battery)
                           │
                       [ R11 150kΩ ]
                           │
                          GND

  VBAT ──● LED1 common anode
         ├─ red   ──[ R7 470Ω ]──┐
         ├─ green ──[ R8 220Ω ]──┼─┐
         └─ blue  ──[ R9 220Ω ]──┼─┼─┐   (drains)
                                 │ │ │
  D7/GPIO17 ──gate─ Q2 ──────────┘ │ │
  D8/GPIO19 ──gate─ Q3 ────────────┘ │
  D9/GPIO20 ──gate─ Q4 ──────────────┘
                    └── all sources → GND
```

> Pins recap (custom PCB): IR = D10/GPIO18, batt sense = D0/GPIO0, LED gates = D7/D8/D9, VBUS = D1.
> D2–D6 stay free. Gate pulldowns on Q2/Q3/Q4 are optional — LEDC drives the gates low within a
> few ms of boot and holds them low in light sleep; add 100 kΩ gate→GND only to kill boot-flicker.

### Build notes

- **Gate pulldown is not optional on a battery device.** While the XIAO boots or deep-sleeps,
  GPIO18 is high-impedance; R4 (100 kΩ) keeps Q1 off so the LEDs can't sit half-on and quietly
  drain the cell.
- **Ballast sizing:** `R = (VBAT − Vf − Vds(on)) / I`. With Vf ≈ 1.5 V @ 150 mA and Vds(on) ≈ 0,
  `(4.2 − 1.5) / 0.15 ≈ 18 Ω`. Current tapers to ~100 mA at a 3.3 V cell — range falls gracefully
  with charge. Burst dissipation ≈ 0.15²·18 ≈ 0.4 W peak, ~0.13 W average at 33 % duty, and only
  during the ~300 ms `CONFIG_ESPIR_SEND_HOLD_MS` send window, so a ¼ W part runs cool. To rescale:
  pick your per-LED current `I`, recompute `R`, and confirm `R`'s wattage ≥ `I²·R`. For more LEDs,
  add a parallel `R + LED` leg each (Q1 carries the sum — AO3400A is good for well over 1 A).
- **More range if needed:** the 940 nm emitters are rated 350 mA continuous, so 18 Ω (~150 mA)
  is deliberately conservative for battery life. If the appliance doesn't respond reliably, drop
  the ballast for more reach — ≈10 Ω → ~250 mA or ≈8.2 Ω → ~300 mA per LED — but then use ½ W
  ballasts and larger `C1/C2` to feed the bigger (2× peak) bursts without sagging the cell.

  | Ballast | ~Peak / LED | Resistor | Trade-off |
  |---------|-------------|----------|-----------|
  | **18 Ω** | ~150 mA | ¼ W | default — longest battery life |
  | ~10 Ω | ~250 mA | ½ W | more range |
  | ~8.2 Ω | ~300 mA | ½ W | near the 350 mA rating; size `C1/C2` for the bursts |
- **Reservoir cap** supplies the ~300 mA pulse bursts (2 LEDs × 150 mA) so the small LiPo doesn't
  sag and brown out the XIAO — same reason the SZHJW build wants a cap, more important here.
- **XIAO as SMD:** the module has 2×7 castellated edge pads (2.54 mm pitch) plus two `BAT+`/`BAT−`
  pads on the underside. Reflow on the castellations and add matching pads (or a cutout) under the
  BAT pads on your carrier. Keep the USB-C edge clear of the board outline for charging/flashing.
  Seeed publishes a KiCad/EAGLE "XIAO" footprint you can drop in.
- **Battery connector (CN1):** these cells use a **JST 1.25 mm (MX1.25) 2P** plug — a 1.25 mm-pitch
  part, *not* the 2.0 mm JST-PH. Fit the matching MX1.25 header and **check polarity before first
  plug-in**: 1.25 mm LiPo plugs aren't polarity-standardised between vendors, and the XIAO `BAT+`
  pad feeds its charger directly, so a reversed cell can damage the board. Confirm the header's
  `BAT+` pin lines up with the cell's positive lead.
- **On/off switch (SW1):** a slide switch in series in the `BAT+` line, between CN1 and the XIAO
  `BAT+` pad. OFF disconnects the cell, so there's **zero battery drain in storage**. It's a battery
  *disconnect*, not a hard kill: the XIAO still runs from USB whenever it's plugged in (its own
  USB-C feeds the regulator), and **charging only happens with SW1 ON** (charge current flows through
  it). A ~300 mA-rated switch is plenty — `C1/C2` buffers the IR peaks, so SW1 only carries the burst
  *average* (~100–150 mA) plus the XIAO's charge current. Wire common + one throw; leave the third
  pin NC. Put SW1 on the cell side so `C1/C2`/`C3` and the divider all sit on the switched `VBAT`.
- **Still no 5 V on battery**, so the LEDs run at `VBAT` and range is shorter than the 5 V master.
  If that isn't enough, the optional 3.3 V→5 V boost from the Notes above can feed `VBAT` of the
  LED leg (the GPIO/MOSFET gate stays at 3.3 V) — resize R1/R2 for the higher rail.

### Flashing (sleepy end device — mind the wake window)

The XIAO C6 exposes only the **native USB-Serial-JTAG** (no UART bridge), and once the firmware
runs it's a Zigbee **sleepy end device** — the serial only answers for a brief window right after
a reset. A plain `idf.py -p /dev/ttyACM0 flash` usually fails with `OSError: [Errno 71] Protocol
error` (esptool's `default_reset` toggles RTS on the CDC-ACM link, and/or the chip is already
asleep); changing `--before` does not help.

Reliable method — hammer `write_flash` in a loop, then reset the board so an attempt lands in the
wake window (usually within a few dozen tries). From `slave-pcb/build`:

```sh
. ~/esp/esp-idf/export.sh
while true; do
  python -m esptool --chip esp32c6 -p /dev/ttyACM0 -b 460800 \
    --before default_reset --after hard_reset --connect-attempts 1 \
    write_flash @flash_args && break
  sleep 0.3
done
```

Holding **BOOT** while tapping **RESET** forces ROM download mode = unlimited window (cleanest if
the loop keeps missing). This wired flash is a one-time step to get onto the OTA dual-slot layout;
afterwards updates go wireless via Zigbee OTA (`AGENTS.md` → *OTA release*).

### Netlist (refdes + nets)

A full connection list for laying out / ERC-checking the board, using the same refdes as the
schematic: U1 = XIAO, U2/U3 = IR LEDs, Q1 = IR FET, Q2/Q3/Q4 = RGB colour FETs, LED1 = RGB LED,
R1/R2 = IR ballast, R3/R4 = IR gate series/pulldown, R5/R6 = battery divider, R7/R8/R9 = RGB
ballasts, R10/R11 = VBUS divider, C1/C2 = reservoir, C3 = decoupling, CN1 = battery connector,
SW1 = on/off. The RGB LED is **common-anode** (anode on `VBAT`), switched low-side by Q2/Q3/Q4.
SW1 is in series in the `BAT+` line (`VCELL` → `VBAT`). XIAO pin numbers follow the 24-pin module
symbol (`+`/`−` = the bottom `BAT+`/`BAT−` pads).

| Net | Pins |
|-----|---|
| **GND** | U1.GND(13), U1.GND(16), U1.−(24), CN1.2, Q1.S, Q2.S, Q3.S, Q4.S, R4.2, R6.2, R11.2, C1.−, C2.−, C3.− |
| **VCELL** (cell + before the switch) | CN1.1, SW1.2 (common) |
| **VBAT** (switched BAT+; IR + RGB + XIAO) | U1.+(23), SW1.1 (throw), R1.1, R2.1, R5.1, LED1.A, C1.+, C2.+, C3.+ |
| **V5** (USB 5 V rail) | U1.5V(14), R10.1 |
| **3V3** (regulator out; unused) | U1.3V3(12), U1.3V3(18) |
| **IR_DRIVE** | U1.D10(11), R3.1 |
| **GATE** | R3.2, Q1.G, R4.1 |
| **IR_U2_A** | R1.2, U2.A |
| **IR_U3_A** | R2.2, U3.A |
| **IR_RTN** (drain) | Q1.D, U2.K, U3.K |
| **BATT_SENSE** | R5.2, R6.1, U1.D0(1) |
| **VBUS_SENSE** | R10.2, R11.1, U1.D1(2) |
| **LEDR_G** (red gate) | U1.D7(8), Q2.G |
| **RGB_R** | LED1.R, R7.1 |
| **QR_D** | R7.2, Q2.D |
| **LEDG_G** (green gate) | U1.D8(9), Q3.G |
| **RGB_G** | LED1.G, R8.1 |
| **QG_D** | R8.2, Q3.D |
| **LEDB_G** (blue gate) | U1.D9(10), Q4.G |
| **RGB_B** | LED1.B, R9.1 |
| **QB_D** | R9.2, Q4.D |

**No-connect** (flag NC for ERC): U1 D2(3), D3(4), D4(5), D5(6), D6(7), MTCK(17), MTDI(15),
MTDI(19), EN(20), MTMS(21), BOOT(22); SW1.3 (unused throw). SW1 pin 2 = common — verify against the
SS12D07VG6 footprint.

> Per IR leg: `VBAT → R(18 Ω) → LED.A → LED.K → Q1.D → Q1.S → GND` (ballast may sit either side of
> the LED). Per RGB colour: `VBAT → LED1 anode → colour die → Rx → Qx.D → Qx.S → GND`, gate from the
> D-pin. The FETs make the LED **active-high**, so keep `CONFIG_ESPIR_LED_COMMON_ANODE=n` despite the
> common-anode package. Optional 100 kΩ gate→GND pulldowns on Q2/Q3/Q4 kill any boot-flicker.

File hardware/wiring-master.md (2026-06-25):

# Wiring — Master (ESP32-C6-DevKitC-1 + SZHJW + VS1838B)

The master uses two simple IR parts straight on the ESP32-C6 **RMT** peripheral:
- **SZHJW** dual-LED transmitter — **sending** (software 38 kHz carrier, 5 V, strong).
- **VS1838B** (or TSOP38238) 38 kHz receiver — **learning** (raw capture). Powered at 3.3 V
  so its output is GPIO-safe; no level shifter needed.

Raw capture learns essentially **any** remote; NEC is auto-compacted for cheap storage/replication.

USB-powered. (The YS-IRTM module is no longer used.)

## Pin assignments (defaults — override in `menuconfig` → ESPIR Configuration)

| Signal | C6 GPIO | Connects to |
|---|---|---|
| IR TX data | **GPIO6** | SZHJW `DAT` |
| IR RX data | **GPIO4** | VS1838B `OUT` |
| 5 V | `5V` pin | SZHJW `VCC` |
| 3.3 V | `3V3` pin | VS1838B `VCC` — **3.3 V only** (output drives a GPIO) |
| GND | any `GND` | SZHJW `GND` **and** VS1838B `GND` |

```
DevKitC-1                         SZHJW dual-LED TX (5 V) — SEND
  5V    ──────────────────────────► VCC
  GPIO6 ──────────────────────────► DAT
  GND ──────────────┬─────────────► GND
                    │
  3V3 ──────────────┼─────────────► VCC   VS1838B receiver (3.3 V ONLY) — LEARN
  GPIO4 ◄───────────┼────────────── OUT
  GND ──────────────┴─────────────► GND
```

## OLED status display (optional)

A 0.91″ **SSD1306** 128×32 I²C OLED shows the live selected slot and learn status. Its `SCK`
silkscreen pin is the I²C **clock (SCL)** — this is an I²C module, not SPI. Default address 0x3C.

| Signal | C6 GPIO | Connects to |
|---|---|---|
| I²C SDA | **GPIO22** | OLED `SDA` |
| I²C SCL | **GPIO23** | OLED `SCK` (= SCL) |
| 3.3 V | `3V3` pin | OLED `VCC` — **3.3 V** |
| GND | any `GND` | OLED `GND` |

```text
DevKitC-1                         SSD1306 0.91" OLED (I2C, 3.3 V)
  3V3   ──────────────────────────► VCC
  GND   ──────────────────────────► GND
  GPIO22 ─────────────────────────► SDA
  GPIO23 ─────────────────────────► SCK (= SCL)
```

Pins are overridable in `menuconfig → ESPIR Configuration` (`ESPIR_OLED_SDA_GPIO`,
`ESPIR_OLED_SCL_GPIO`, `ESPIR_OLED_I2C_ADDR`); set `ESPIR_OLED_ENABLE=n` to omit the panel.
The display is optional — if absent, the firmware logs a warning and runs normally.

## Notes

- **Power the VS1838B at 3.3 V**, never 5 V — its `OUT` goes straight to `GPIO4`.
- The SZHJW has its own transistor driver; the 3.3 V GPIO drives `DAT` fine. Put `VCC` at 5 V
  for full ~1–3 m range; a `~38–100 µF` cap across `VCC`/`GND` stiffens the LED pulses.
- Aim the VS1838B toward where you'll hold the remote; aim the SZHJW LEDs at the appliance.
- Avoid GPIO12/13 (USB-Serial-JTAG) and strapping pins GPIO8/9/15. GPIO4/6 are clear.
- **Learns any protocol** (raw envelope); NEC/RC5/etc. all work. No NEC-only limitation.
- Logs/flashing go over the DevKitC's CH343 USB-UART port (console = UART0), not the native
  USB-Serial-JTAG port — see `AGENTS.md`.

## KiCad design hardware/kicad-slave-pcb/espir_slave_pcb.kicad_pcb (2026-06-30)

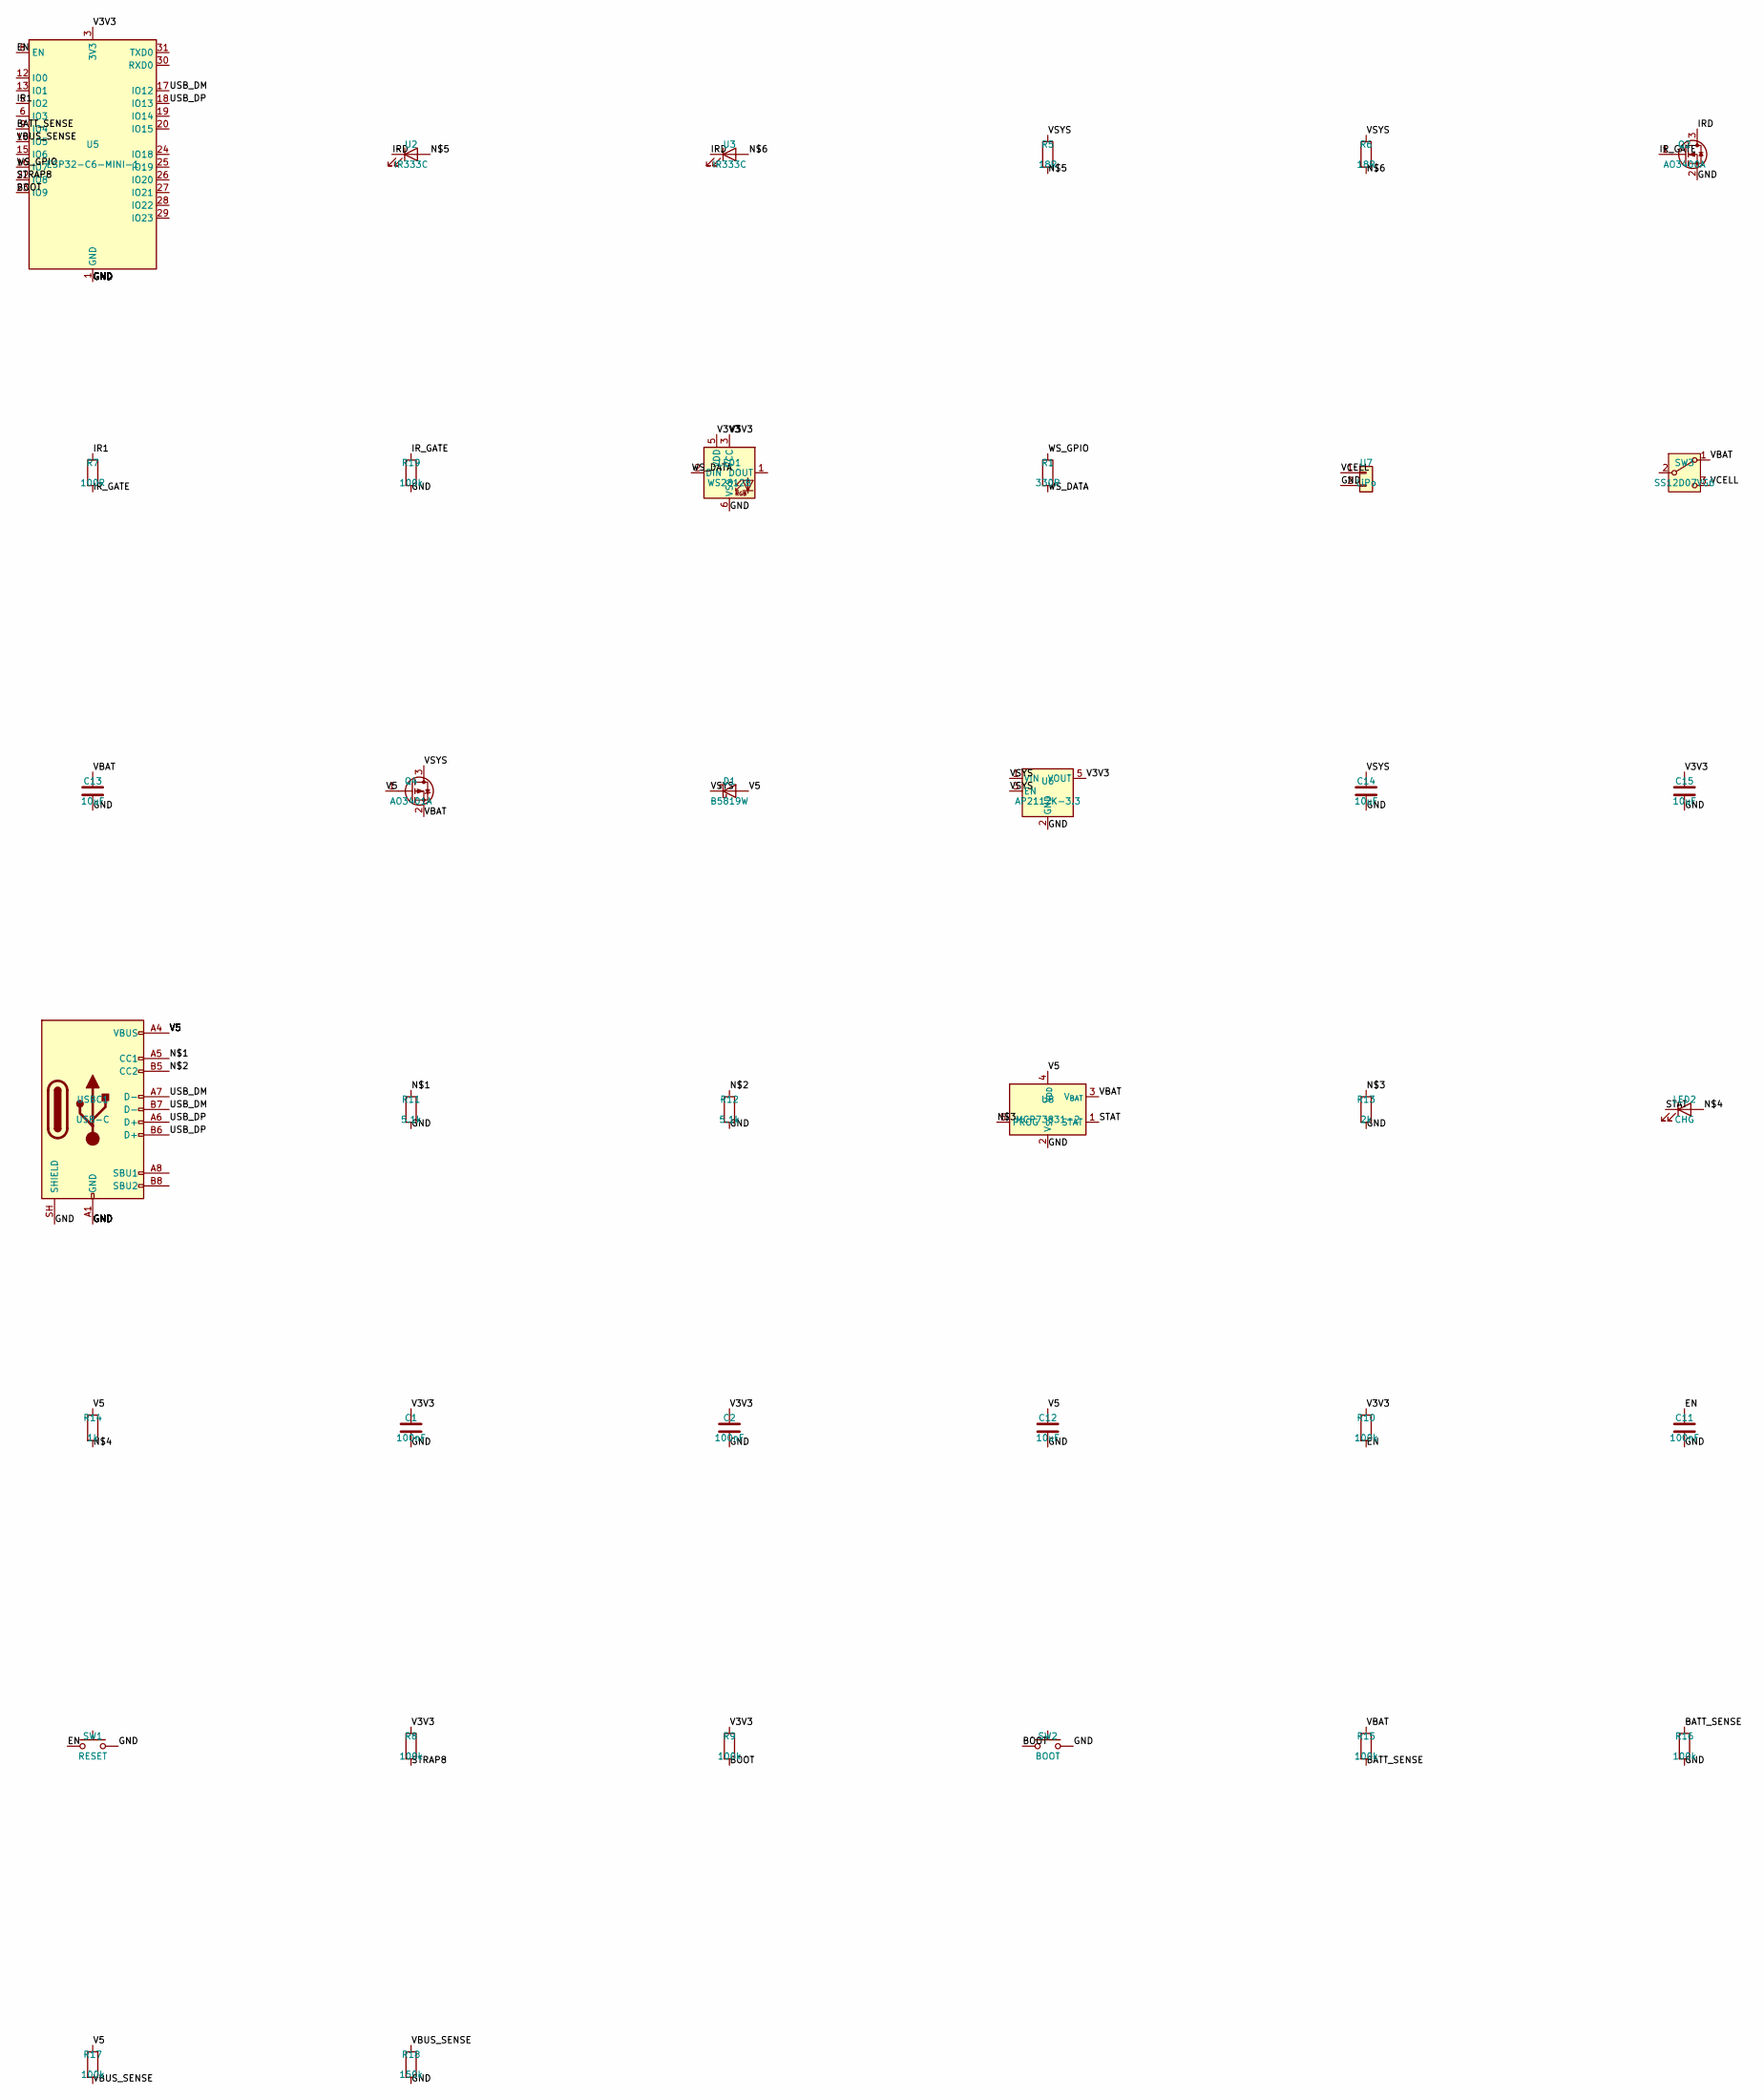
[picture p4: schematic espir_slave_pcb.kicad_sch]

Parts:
C1, C2, C11: 100nF; C_0603_1608Metric
C12, C13, C14, C15: 10uF; C_0805_2012Metric
D1: B5819W; D_SOD-123
LED1: WS2812B; LED_WS2812_PLCC6_5.0x5.0mm_P1.6mm
LED2: CHG; LED_0603_1608Metric
Q2: AO3400A; SOT-23
Q4: AO3401A; SOT-23
R1: 330R; R_0603_1608Metric
R5, R6: 18R; R_0603_1608Metric
R7: 100R; R_0603_1608Metric
R8, R9, R10, R15, R16, R17, R19: 100k; R_0603_1608Metric
R11, R12: 5.1k; R_0603_1608Metric
R13: 2k; R_0603_1608Metric
R14: 1k; R_0603_1608Metric
R18: 150k; R_0603_1608Metric
SW1: RESET; SW_PUSH_6mm
SW2: BOOT; SW_PUSH_6mm
SW3: SS12D07VG6; SW_SPDT_Shouhan_MSK12C02
U2, U3: IR333C; LED_D5.0mm
U5: ESP32-C6-MINI-1
U6: AP2112K-3.3; SOT-23-5
U7: LiPo; JST_SH_SM02B-SRSS-TB_1x02-1MP_P1.00mm_Horizontal
U8: MCP73831-2; SOT-23-5
USBC1: USB-C; USB_C_Receptacle_HRO_TYPE-C-31-M-12

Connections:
BATT_SENSE: R15.2, R16.1, U5.9 (IO4)
BOOT: R9.2, SW2.1, U5.23 (IO9)
EN: C11.1, R10.2, SW1.1, U5.8 (EN)
GND: C1.2, C2.2, C11.2, C12.2, C13.2, C14.2, C15.2, LED1.6 (VSS), Q2.2 (S), R11.2, R12.2, R13.2, R16.2, R18.2, R19.2, SW1.2, SW2.2, U5.1 (GND), U5.2 (GND), U5.11 (GND), U5.14 (GND), U5.36 (GND), U5.37 (GND), U5.38 (GND), U5.39 (GND), U5.40 (GND), U5.41 (GND), U5.42 (GND), U5.43 (GND), U5.44 (GND), U5.45 (GND), U5.46 (GND), U5.47 (GND), U5.48 (GND), U5.49 (GND), U5.50 (GND), U5.51 (GND), U5.52 (GND), U5.53 (GND), U6.2 (GND), U7.2, U8.2 (V_{SS}), USBC1.A1 (GND), USBC1.A12 (GND), USBC1.B1 (GND), USBC1.B12 (GND), USBC1.SH (SHIELD)
IR1: R7.1, U5.5 (IO2)
IRD: Q2.3 (D), U2.1 (K), U3.1 (K)
IR_GATE: Q2.1 (G), R7.2, R19.1
unnamed: R11.1, USBC1.A5 (CC1)
unnamed: R12.1, USBC1.B5 (CC2)
unnamed: R13.1, U8.5 (PROG)
unnamed: LED2.2 (A), R14.2
unnamed: R5.2, U2.2 (A)
unnamed: R6.2, U3.2 (A)
STAT: LED2.1 (K), U8.1 (STAT)
STRAP8: R8.2, U5.22 (IO8)
USB_DM: U5.17 (IO12), USBC1.A7 (D-), USBC1.B7 (D-)
USB_DP: U5.18 (IO13), USBC1.A6 (D+), USBC1.B6 (D+)
V3V3: C1.1, C2.1, C15.1, LED1.3 (VCC), LED1.5 (VDD), R8.1, R9.1, R10.1, U5.3 (3V3), U6.5 (VOUT)
V5: C12.1, D1.2 (A), Q4.1 (G), R14.1, R17.1, U8.4 (V_{DD}), USBC1.A4 (VBUS), USBC1.A9 (VBUS), USBC1.B4 (VBUS), USBC1.B9 (VBUS)
VBAT: C13.1, Q4.2 (S), R15.1, SW3.1 (A), U8.3 (V_{BAT})
VBUS_SENSE: R17.2, R18.1, U5.10 (IO5)
VCELL: SW3.3 (C), U7.1
VSYS: C14.1, D1.1 (K), Q4.3 (D), R5.1, R6.1, U6.1 (VIN), U6.3 (EN)
WS_DATA: LED1.2 (DIN), R1.2
WS_GPIO: R1.1, U5.16 (IO7)

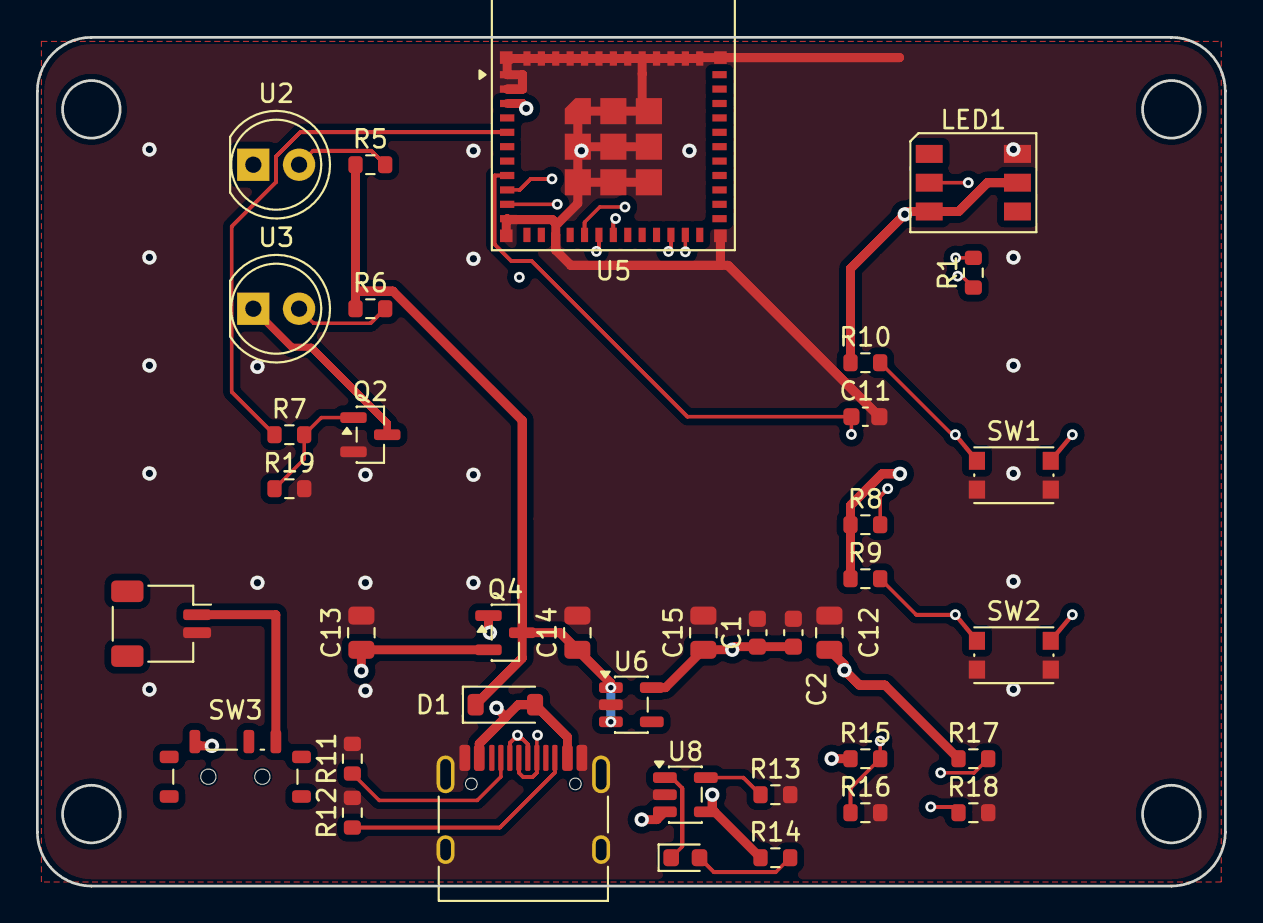
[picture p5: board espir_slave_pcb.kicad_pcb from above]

Board: 4 copper layers, 66.0 x 47.1 mm, 38 parts (0 on the bottom side), 25 nets.

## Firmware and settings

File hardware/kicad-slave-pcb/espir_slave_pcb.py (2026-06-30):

#!/usr/bin/env python3
"""
ESPIR slave PCB — circuit-as-code for KiCad (SKiDL).

This is the KiCad realization of the ESPIR fully-custom slave board originally
captured in EasyEDA Pro (see ../pcb-fully-custom.md). It is built with SKiDL:
the circuit is described in Python, which generates an authoritative KiCad
netlist (espir_slave_pcb.net). The netlist is then turned into a .kicad_pcb
(footprints + nets + ratsnest) with kinet2pcb — see build.sh.

ADJUSTMENT vs the EasyEDA discrete-C6 board (per request: use ESP32-C6-MINI-1):
  The bare ESP32-C6 QFN-40 is replaced by the ESP32-C6-MINI-1 module, which
  already integrates the SPI flash (W25Q32), the 40 MHz crystal + load caps,
  the RF chip antenna + pi-match, and the QFN EP grounding. So this design
  DROPS those discrete parts entirely:
      - U4  W25Q32 flash + its decoupling          -> internal to module
      - X1  40 MHz crystal + C9/C10 load caps       -> internal to module
      - AE1 chip antenna, RF1 u.FL, R2/R3/R4 pi-match-> internal to module
  Everything else carries over: USB-C + load-share + LiPo charger power tree,
  AP2112K 3V3 LDO, 2-LED discrete IR driver, addressable RGB status LED,
  battery/VBUS sense dividers, reset/boot buttons, battery slide switch.

  GPIO REMAP: the module does not bring out GPIO11, so the WS2812 status-LED
  data line moves GPIO11 -> GPIO7 (IO7, a free non-strapping pin). IR stays on
  GPIO2; battery/VBUS sense on GPIO4/GPIO5; USB on GPIO12/13; boot on GPIO9.

Run:  python espir_slave_pcb.py   (emits espir_slave_pcb.net + runs ERC)
"""

from skidl import (Part, Net, TEMPLATE, generate_netlist, ERC, set_default_tool,
                   KICAD9, POWER)
import skidl

set_default_tool(KICAD9)

# ----------------------------------------------------------------------------
# Footprint short-hands
# ----------------------------------------------------------------------------
R0603  = "Resistor_SMD:R_0603_1608Metric"
C0603  = "Capacitor_SMD:C_0603_1608Metric"
C0805  = "Capacitor_SMD:C_0805_2012Metric"
SOT235 = "Package_TO_SOT_SMD:SOT-23-5"
SOT23  = "Package_TO_SOT_SMD:SOT-23"

# ----------------------------------------------------------------------------
# Nets (the rails / signals of the board)
# ----------------------------------------------------------------------------
GND   = Net('GND')
V5    = Net('V5')          # USB VBUS, 5 V
VSYS  = Net('VSYS')        # system rail after load-share (USB-or-battery)
VBAT  = Net('VBAT')        # battery rail (downstream of the slide switch)
VCELL = Net('VCELL')       # raw cell terminal (upstream of the slide switch)
V3V3  = Net('V3V3')        # AP2112K output, powers the module

IR_GATE = Net('IR_GATE')   # GPIO2 -> series R -> Q2 gate
IRD     = Net('IRD')       # IR-LED cathodes <-> Q2 drain (pulsed LED current)
WS_DATA = Net('WS_DATA')   # GPIO7 -> series R -> WS2812 DIN  (was GPIO11)
USB_DP  = Net('USB_DP')    # GPIO13
USB_DM  = Net('USB_DM')    # GPIO12
BATT_SENSE = Net('BATT_SENSE')  # GPIO4 (ADC1)
VBUS_SENSE = Net('VBUS_SENSE')  # GPIO5 (ADC1)
EN      = Net('EN')        # module reset
BOOT    = Net('BOOT')      # GPIO9 download-mode button
STAT    = Net('STAT')      # MCP73831 open-drain charge status
IR1     = Net('IR1')       # GPIO2 raw drive (pre series-R)
WS_GPIO = Net('WS_GPIO')   # GPIO7 raw drive (pre series-R)
STRAP8  = Net('STRAP8')    # GPIO8 strap pull-up node

# Mark the source rails as driven so ERC doesn't flag power-input-not-driven.
# (V3V3 is driven by the LDO VOUT and VBAT by the charger, so they don't need it.)
for rail in (GND, V5, VSYS):
    rail.drive = POWER

# ----------------------------------------------------------------------------
# U5 — ESP32-C6-MINI-1 module (MCU + radio + flash + crystal + antenna)
# ----------------------------------------------------------------------------
U5 = Part('RF_Module', 'ESP32-C6-MINI-1', value='ESP32-C6-MINI-1',
          footprint='RF_Module:ESP32-C6-MINI-1')
U5.ref = 'U5'
U5['3V3'] += V3V3
U5['GND'] += GND          # all GND pins (incl. module EP) -> GND
U5['EN']  += EN
U5['IO2'] += IR1          # GPIO2 IR drive (pre series-R)
U5['IO7'] += WS_GPIO      # GPIO7 status-LED drive (pre series-R)
U5['IO4'] += BATT_SENSE
U5['IO5'] += VBUS_SENSE
U5['IO12'] += USB_DM      # USB D-
U5['IO13'] += USB_DP      # USB D+
U5['IO9'] += BOOT         # boot/download button
# Strapping pin GPIO8 needs a pull-up for normal boot.
U5['IO8'] += STRAP8
# Module NC pins and spare GPIOs (IO0/1/3/6/14/15/18-23, RXD0/TXD0) are left
# intentionally unconnected (free for future use).

# ----------------------------------------------------------------------------
# Power input: USB-C receptacle (VBUS, CC pulldowns, D+/D-)
# ----------------------------------------------------------------------------
USBC1 = Part('Connector', 'USB_C_Receptacle_USB2.0_16P', value='USB-C',
             footprint='Connector_USB:USB_C_Receptacle_HRO_TYPE-C-31-M-12')
USBC1.ref = 'USBC1'
USBC1['VBUS'] += V5       # all 4 VBUS pins
USBC1['GND']  += GND      # all 4 GND pins
USBC1['SHIELD'] += GND
USBC1['D+'] += USB_DP     # A6 & B6 tied (USB2.0)
USBC1['D-'] += USB_DM     # A7 & B7 tied
# SBU1/SBU2 left unconnected (no alt-mode)

R11 = Part('Device', 'R', value='5.1k', footprint=R0603, ref='R11')  # CC1 pulldown
R12 = Part('Device', 'R', value='5.1k', footprint=R0603, ref='R12')  # CC2 pulldown
USBC1['CC1'] += R11[1]; R11[2] += GND
USBC1['CC2'] += R12[1]; R12[2] += GND

# ----------------------------------------------------------------------------
# LiPo charger — MCP73831 (VBUS -> VBAT), STAT LED, PROG sets current
# ----------------------------------------------------------------------------
U8 = Part('Battery_Management', 'MCP73831-2-OT', value='MCP73831-2',
          footprint=SOT235, ref='U8')
# Pin names carry LaTeX braces (V_{DD}); address by number: 1 STAT,2 VSS,3 VBAT,4 VDD,5 PROG
U8[4] += V5      # VDD
U8[2] += GND     # VSS
U8[3] += VBAT    # VBAT
U8[1] += STAT    # STAT
R13 = Part('Device', 'R', value='2k', footprint=R0603, ref='R13')    # PROG ~500 mA
U8[5] += R13[1]; R13[2] += GND

LED2 = Part('Device', 'LED', value='CHG', footprint="LED_SMD:LED_0603_1608Metric",
            ref='LED2')
R14 = Part('Device', 'R', value='1k', footprint=R0603, ref='R14')
V5 += R14[1]; R14[2] += LED2['A']; LED2['K'] += STAT  # lights while charging

# ----------------------------------------------------------------------------
# Power path: load-share P-FET (Q4) + OR-ing Schottky (D1), battery slide switch
# ----------------------------------------------------------------------------
# USB present: V5 -> D1 -> VSYS. On battery: V5=0 -> Q4 on -> VBAT -> VSYS.
D1 = Part('Diode', '1N5819', value='B5819W', footprint="Diode_SMD:D_SOD-123",
          ref='D1')
D1['A'] += V5; D1['K'] += VSYS

Q4 = Part('Transistor_FET', 'AO3401A', value='AO3401A', footprint=SOT23, ref='Q4')
Q4['S'] += VBAT          # source at battery
Q4['G'] += V5            # gate = VBUS -> off when USB present
Q4['D'] += VSYS          # drain to system rail

# Battery connector + slide-switch disconnect (cell -> SW3 -> VBAT)
U7 = Part('Connector_Generic', 'Conn_01x02', value='LiPo',
          footprint='Connector_JST:JST_SH_SM02B-SRSS-TB_1x02-1MP_P1.00mm_Horizontal',
          ref='U7')
U7[1] += VCELL; U7[2] += GND
SW3 = Part('Switch', 'SW_SPDT', value='SS12D07VG6',
           footprint='Button_Switch_SMD:SW_SPDT_Shouhan_MSK12C02', ref='SW3')
SW3[3] += VCELL          # common -> cell
SW3[1] += VBAT           # ON throw -> battery rail
# SW3[2] OFF throw left unconnected

# ----------------------------------------------------------------------------
# 3V3 regulation — AP2112K-3.3 LDO (VSYS -> 3V3)
# ----------------------------------------------------------------------------
U6 = Part('Regulator_Linear', 'AP2112K-3.3', value='AP2112K-3.3',
          footprint=SOT235, ref='U6')
U6['VIN'] += VSYS
U6['EN']  += VSYS        # always-on
U6['GND'] += GND
U6['VOUT'] += V3V3
# U6 NC pin left unconnected

# ----------------------------------------------------------------------------
# Bulk + decoupling
# ----------------------------------------------------------------------------
C12 = Part('Device', 'C', value='10uF', footprint=C0805, ref='C12'); V5   += C12[1]; C12[2] += GND
C13 = Part('Device', 'C', value='10uF', footprint=C0805, ref='C13'); VBAT += C13[1]; C13[2] += GND
C14 = Part('Device', 'C', value='10uF', footprint=C0805, ref='C14'); VSYS += C14[1]; C14[2] += GND
C15 = Part('Device', 'C', value='10uF', footprint=C0805, ref='C15'); V3V3 += C15[1]; C15[2] += GND
C1  = Part('Device', 'C', value='100nF', footprint=C0603, ref='C1');  V3V3 += C1[1];  C1[2]  += GND  # module 3V3 bypass
C2  = Part('Device', 'C', value='100nF', footprint=C0603, ref='C2');  V3V3 += C2[1];  C2[2]  += GND

# ----------------------------------------------------------------------------
# Reset (EN) + boot (GPIO9) buttons and straps
# ----------------------------------------------------------------------------
R10 = Part('Device', 'R', value='100k', footprint=R0603, ref='R10'); V3V3 += R10[1]; R10[2] += EN     # EN pull-up
C11 = Part('Device', 'C', value='100nF', footprint=C0603, ref='C11'); EN  += C11[1]; C11[2] += GND    # EN cap
SW1 = Part('Switch', 'SW_Push', value='RESET',
           footprint='Button_Switch_SMD:SW_Push_1P1T_NO_CK_KMR2', ref='SW1')
SW1[1] += EN;   SW1[2] += GND
SW2 = Part('Switch', 'SW_Push', value='BOOT',
           footprint='Button_Switch_SMD:SW_Push_1P1T_NO_CK_KMR2', ref='SW2')
SW2[1] += BOOT; SW2[2] += GND
R8 = Part('Device', 'R', value='100k', footprint=R0603, ref='R8'); V3V3 += R8[1]; R8[2] += STRAP8   # GPIO8 strap pull-up
R9 = Part('Device', 'R', value='100k', footprint=R0603, ref='R9'); V3V3 += R9[1]; R9[2] += BOOT     # GPIO9 strap pull-up

# ----------------------------------------------------------------------------
# IR sender — GPIO2 -> R7 -> Q2 gate (with pulldown); 2 IR LEDs on VSYS via R5/R6
# ----------------------------------------------------------------------------
R7  = Part('Device', 'R', value='100R', footprint=R0603, ref='R7')  # gate series
IR1 += R7[1]; R7[2] += IR_GATE
Rgpd = Part('Device', 'R', value='100k', footprint=R0603, ref='R19')  # gate pulldown
IR_GATE += Rgpd[1]; Rgpd[2] += GND
Q2 = Part('Transistor_FET', 'AO3400A', value='AO3400A', footprint=SOT23, ref='Q2')
Q2['G'] += IR_GATE; Q2['S'] += GND; Q2['D'] += IRD
R5 = Part('Device', 'R', value='18R', footprint=R0603, ref='R5')
R6 = Part('Device', 'R', value='18R', footprint=R0603, ref='R6')
U2 = Part('Device', 'LED', value='IR333C', footprint='LED_THT:LED_D5.0mm', ref='U2')
U3 = Part('Device', 'LED', value='IR333C', footprint='LED_THT:LED_D5.0mm', ref='U3')
VSYS += R5[1]; R5[2] += U2['A']; U2['K'] += IRD
VSYS += R6[1]; R6[2] += U3['A']; U3['K'] += IRD

# ----------------------------------------------------------------------------
# Addressable RGB status LED — GPIO7 -> R1 -> WS2812 DIN  (powered from 3V3)
# ----------------------------------------------------------------------------
R1 = Part('Device', 'R', value='330R', footprint=R0603, ref='R1')
WS_GPIO += R1[1]; R1[2] += WS_DATA
LED1 = Part('LED', 'WS2812', value='WS2812B',
            footprint='LED_SMD:LED_WS2812_PLCC6_5.0x5.0mm_P1.6mm', ref='LED1')
LED1['VDD'] += V3V3
LED1['VCC'] += V3V3
LED1['VSS'] += GND
LED1['DIN'] += WS_DATA
# DOUT (no daisy-chain) and NC left unconnected

# ----------------------------------------------------------------------------
# Telemetry dividers — battery -> GPIO4, VBUS-present -> GPIO5
# ----------------------------------------------------------------------------
R15 = Part('Device', 'R', value='100k', footprint=R0603, ref='R15')
R16 = Part('Device', 'R', value='100k', footprint=R0603, ref='R16')
VBAT += R15[1]; R15[2] += BATT_SENSE; BATT_SENSE += R16[1]; R16[2] += GND
R17 = Part('Device', 'R', value='100k', footprint=R0603, ref='R17')
R18 = Part('Device', 'R', value='150k', footprint=R0603, ref='R18')
V5 += R17[1]; R17[2] += VBUS_SENSE; VBUS_SENSE += R18[1]; R18[2] += GND

# ----------------------------------------------------------------------------
if __name__ == '__main__':
    ERC()
    generate_netlist()

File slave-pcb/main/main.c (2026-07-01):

/*
 * ESPIR custom-PCB slave — same battery (LiPo) Zigbee Sleepy End Device as slave/, but on a
 * purpose-built carrier PCB: the XIAO ESP32-C6 is reflowed on, the SZHJW module is replaced by
 * a discrete MOSFET IR driver on the same GPIO, and a discrete RGB LED shows status:
 *   amber blink = searching for the network, green = joined, blue rapid blink = sending.
 * The green is gated on USB power so a steady LED can't flatten the battery (see espir_led.h).
 */
#include "esp_err.h"
#include "esp_log.h"
#include "sdkconfig.h"
#include "driver/gpio.h"

#include "espir_ir.h"
#include "espir_store.h"
#include "espir_device.h"
#include "espir_led.h"

static const char *TAG = "espir-slave-pcb";

/* XIAO ESP32-C6 antenna RF switch: GPIO3 LOW enables the switch; GPIO14 selects the antenna
 * (LOW = onboard ceramic, HIGH = external U.FL). Required or the radio can't reach the network. */
static void xiao_antenna_init(void)
{
    gpio_config_t cfg = {
        .pin_bit_mask = (1ULL << 3) | (1ULL << 14),
        .mode = GPIO_MODE_OUTPUT,
    };
    gpio_config(&cfg);
    gpio_set_level(3, 0);   /* enable RF switch */
#ifdef CONFIG_ESPIR_XIAO_EXT_ANTENNA
    gpio_set_level(14, 1);  /* external U.FL */
    ESP_LOGI(TAG, "XIAO antenna: external U.FL");
#else
    gpio_set_level(14, 0);  /* onboard ceramic */
    ESP_LOGI(TAG, "XIAO antenna: onboard");
#endif
}

/* Map the device's high-level state onto the RGB LED animation. */
static void on_status(espir_status_t st)
{
    switch (st) {
    case ESPIR_STATUS_SEARCHING: espir_led_set(ESPIR_LED_SEARCHING); break;
    case ESPIR_STATUS_CONNECTED: espir_led_set(ESPIR_LED_CONNECTED); break;
    case ESPIR_STATUS_SENDING:   espir_led_set(ESPIR_LED_SENDING);   break;
    default:                     espir_led_set(ESPIR_LED_OFF);       break;
    }
}

void app_main(void)
{
    xiao_antenna_init();

    bool common_anode = false;
#ifdef CONFIG_ESPIR_LED_COMMON_ANODE
    common_anode = true;
#endif
    espir_led_cfg_t led = {
        .gpio_r       = CONFIG_ESPIR_LED_R_GPIO,
        .gpio_g       = CONFIG_ESPIR_LED_G_GPIO,
        .gpio_b       = CONFIG_ESPIR_LED_B_GPIO,
        .common_anode = common_anode,
    };
    ESP_ERROR_CHECK(espir_led_init(&led));
    espir_led_set(ESPIR_LED_SEARCHING);          /* show "searching" from boot until joined */
    espir_device_set_status_cb(on_status);

    ESP_ERROR_CHECK(espir_store_init());
    ESP_ERROR_CHECK(espir_ir_init(CONFIG_ESPIR_IR_TX_GPIO, -1));  /* transmit only */
    ESP_LOGI(TAG, "ESPIR slave-pcb: %d slots, tx=%d", espir_store_count(), CONFIG_ESPIR_IR_TX_GPIO);

    espir_device_cfg_t cfg = {
        .role = ESPIR_ROLE_SLAVE,
        .manufacturer = "ESPIR",
        .model = "ESPIR-SLAVE",
        .learn_timeout_ms = 0,
        .send_hold_ms = CONFIG_ESPIR_SEND_HOLD_MS,
        .ota = true,
        .ota_image_type = ESPIR_OTA_IMAGE_TYPE_SLAVE_PCB,
        .battery = true,
        .battery_adc_gpio = CONFIG_ESPIR_BATTERY_ADC_GPIO,
        .battery_div_x100 = CONFIG_ESPIR_BATTERY_DIV_X100,
    };
    espir_device_start(&cfg);
}

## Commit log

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2026-06-23 Add Zigbee device module + master app (custom cluster 0xFC00, learn FSM); builds clean
    [partitions.csv]
2026-06-23 Add slave app (sleepy end device, transmit-only); builds clean
    [partitions.csv]
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2026-06-23 Master IR backend: switch to YS-IRTM UART NEC codec
    - New espir_irtm component (YS-IRTM 9600 8N1 driver: transmit/receive NEC)
    - espir_device picks IR backend by role: master=YS-IRTM(UART), slave=SZHJW(RMT)
    - Master learn FSM captures via UART; codes stored as NEC, interoperable with RMT slaves
    - Master app/Kconfig now UART-based (no RMT/VS1838B on master)
    - Docs: README, wiring-master, BOM, spec, AGENTS updated for YS-IRTM (NEC-only, TXD divider)
2026-06-23 Master console on UART0 (CH343 bridge port); document native-USB download trap
    Verified on hardware: master boots, YS-IRTM inits on uart1, Zigbee stack starts and
    attempts network steering. Native USB-Serial-JTAG port resets into download on port-open,
    so logs go to the CH343 UART bridge port instead (console = UART0).
2026-06-23 Fix learn-task stack overflow; quiet empty-slot NVS load
    - Move ~1KB espir_code_t and blob buffers off-stack (static) in learn_task and do_send,
    bump learn task stack to 6144 — fixes crash on first learn capture.
    - espir_store_load: don't ESP_RETURN_ON_ERROR on nvs_open when the namespace is absent
    (fresh device / empty slot) — was logging a spurious error on every empty-slot send.
    Verified on hardware: learn (remote->YS-IRTM->NVS) and send (Z2M->Zigbee->YS-IRTM->IR)
    work end-to-end; learned NEC addr 0x04 cmd 0x04, replayed on command.
    [espir_device.c]
2026-06-23 z2m: slot-selector + action buttons UI; read attrs on configure (no more Null)
    - Replace the learn/send/clear sliders with a 'slot' selector + an 'action' enum
    (Learn/Send/Clear) that issues the command on the selected slot.
    - Add configure() that reads the custom-cluster attributes on join/reconfigure so
    learn_status/last_*/slot_count show real values instead of Null.
    - Keep direct send_slot/learn_slot/clear_slot tz handlers for automations.
    - Drop deferred m.battery() from slave for now.
2026-06-23 Fix Z2M status display (Null) + slider->button UI
    UI: replace learn/send/clear sliders with a 'slot' selector + an 'action' enum
    (Learn/Send/Clear); keep direct send_slot/learn_slot for automations.
    Status decode (was all Null): the custom cluster 0xFC00 wasn't resolving for inbound
    reports in zigbee-herdsman 10.4. Fixes:
    - converter cluster def needs an explicit name AND each attribute needs an explicit
    name (herdsman stores the def verbatim and reads .name; it does not use JS keys)
    - make the cluster manufacturer-specific (ESPIR_MANUF_CODE 0x1037) on both sides so the
    0xFC00 cluster resolves; firmware registers attrs via esp_zb_cluster_add_manufacturer_attr,
    sets via esp_zb_zcl_set_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
    [espir_device.c, espir_proto.h]
2026-06-23 Master: transmit via SZHJW (RMT) for stronger output; YS-IRTM = learn only
    The YS-IRTM's single emitter is weak. Add an SZHJW dual-LED transmitter on the RMT
    peripheral (default GPIO6, 5V) and route master sends through it; the YS-IRTM is kept for
    learning (its receiver). Only one transmitter fires per send (avoids a double-press).
    - espir_device: master do_send uses espir_ir_send (RMT) when cfg.master_rmt_tx
    - master app: espir_ir_init + new Kconfig ESPIR_MASTER_USE_SZHJW (default y) / ESPIR_TX_GPIO (6)
    - docs: wiring-master, bom, README, spec updated
    Verified on hardware: builds clean, boots 'SZHJW tx=6 (RMT)', send via RMT path works.
    [espir_device.c, espir_device.h, main.c]
2026-06-23 Drop YS-IRTM: master learns via VS1838B + sends via SZHJW, both on RMT
    The YS-IRTM is gone. Master now uses the RMT peripheral for both directions, like the slave:
    - transmit via the SZHJW dual-LED module (GPIO6)
    - learn via a VS1838B 38kHz receiver straight to GPIO4 (raw capture, 3.3V, no level shifter)
    Benefits: learns ANY remote protocol (raw envelope; NEC auto-compacted), no UART/NEC-only
    limitation, simpler wiring (no 5V TXD divider).
    - espir_device: do_send always uses espir_ir_send; learn_task uses espir_ir_receive +
    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
2026-06-23 IR learn: capture loop keeps the longest header-led frame (fixes Samsung)
    A held/mashed remote made the RMT RX arm mid-frame and capture a short, header-less
    fragment (e.g. Samsung BN59-01303A); the inter-frame gap then ended reception. Now
    espir_ir_receive re-arms within the learn window, keeps the longest capture, and stops once
    it has a header-led frame (first mark >= 2 ms, >= 20 edges) — so a re-arm during the gap
    catches the next complete frame.
    Verified: Samsung now captures the full 67-edge frame (4546us header) and learns; AC and
    NEC remotes unaffected.
    [espir_ir.c]
2026-06-23 Fix reboot on long (raw) code learn; cap last_code to one ZCL frame
    A long RAW capture (e.g. Samsung TV ~134 B) was reported in the last_code octet-string
    attribute, which overflows a single ZCL report frame and crashed/rebooted the device. The
    code was saved to NVS first (so send worked), but the reboot reset learn_status to idle —
    hence the UI never showed 'captured'.
    - Cap last_code to ESPIR_LAST_CODE_MAX (48 B): NEC and short raw are exposed for replication;
    longer raw codes leave last_code empty (still stored + sendable locally).
    - Guard learn_task against spurious/duplicate triggers (stray 'slot 255').
    Verified on hardware: learning a 134 B raw code now stays up (rebooted: False)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
    [espir_device.c]
2026-06-23 Slave: handle CAN_SLEEP signal (sleepy end device) + TX on D10/GPIO18
    - esp_zb_app_signal_handler: on ESP_ZB_COMMON_SIGNAL_CAN_SLEEP call esp_zb_sleep_now()
    (guarded to the end-device lib variant); was logging the signal thousands of times and
    never actually sleeping.
    - slave IR TX GPIO default 18 (XIAO D10).
    Verified: slave boots, IR init tx=18, no CAN_SLEEP flood; master still links.
2026-06-23 Slave joins: XIAO C6 antenna RF-switch init + run non-sleepy for now
    Root cause the slave never joined: the XIAO ESP32-C6 RF switch was never enabled, so the
    radio couldn't reach the network (coordinator saw zero join attempts). Configure it in the
    slave app: GPIO3=LOW enables the switch, GPIO14 selects antenna (LOW=onboard, HIGH=external
    via CONFIG_ESPIR_XIAO_EXT_ANTENNA).
    Also gate sleep behind CONFIG_PM_ENABLE and disable PM for now (sleeping during commissioning
    also blocks joining) so the slave runs as a non-sleepy ED until join+transmit are verified;
    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
2026-06-23 Slave: re-enable sleep, join-safe (only sleep after joined)
    Sleep is gated on s_joined so the ED stays awake through commissioning (CAN_SLEEP ignored
    until BDB join/rejoin succeeds), then sleeps for battery. Re-enabled CONFIG_PM_ENABLE +
    tickless idle in slave sdkconfig.defaults.
    Verified: sleepy slave rejoins Z2M and reports attributes (joins + sleeps).
2026-06-23 Device-to-device replication: master pushes codes to slaves (long raw works)
    Replaces the HA-shuttle replication (which was capped to one Zigbee frame, so long raw codes
    like Samsung TV couldn't replicate) with direct master->slave copy over Zigbee:
    - proto: add copy_to(slot, ieee) and copy_all(ieee) commands (0x07/0x08).
    - master (espir_device.c): on copy_to/copy_all, load the slot(s) from NVS and send them to the
    target slave's endpoint 10 as program_begin/chunk/commit (chunked, ATTR_TYPE_SET raw bytes,
    64-bit addressing). Reuses the slave's existing program handler, so any length carries.
    - converter: copyTo/copyAll command defs + tzReplicate (replicate_slot / replicate_all).
    - HA: a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
    [espir_device.c, espir_proto.h]
2026-06-23 Send repeats for a hold duration (default 300ms) like holding a remote key
    - espir_device: send now runs in its own task (queue-fed) so a held send never blocks the
    Zigbee stack; send_worker re-transmits the frame with a ~40ms gap until send_hold_ms elapses
    (CONFIG_ESPIR_SEND_HOLD_MS, default 300; 0 = single shot). Added send_hold_ms to the cfg.
    - master/slave Kconfig + main: wire CONFIG_ESPIR_SEND_HOLD_MS.
    - HA: fix the auto-copy automation to a native state trigger (to: captured) so it fires once
    per learn instead of re-replicating on every attribute report.
    Verified: 'sent slot 0 (3 frames over 300ms)' (NEC) and slot 10 (134 B RAW) on the master.
    [espir_device.c, espir_device.h, main.c]
2026-06-23 Slave battery indicator (Power Config cluster) + sleep boot grace window
    - espir_device: read the LiPo via ADC1 (BAT+ ÷2 divider on GPIO0/A0), map 3.30-4.20V to 0-100%,
    and report batteryVoltage + batteryPercentageRemaining over the standard Power Config cluster
    (0x0001) every 10 min. Cluster + sampling only enabled when cfg.battery (slave).
    - cfg gains battery + battery_adc_gpio; slave main enables it (CONFIG_ESPIR_BATTERY_ADC_GPIO=0).
    - converter: slave exposes battery + battery_voltage (fz.battery parses the self-reported cluster).
    - sleep: only sleep after a 12s boot grace window — light sleep drops the native USB-JTAG, so
    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
2026-06-23 Battery: configurable divider ratio (CONFIG_ESPIR_BATTERY_DIV_X100)
    Don't hardcode ÷2 — compute vbat from (R_top+R_bottom)/R_bottom so any resistor pair works.
    Default 200 (1:2). Wiring doc now recommends two 1M + a 100nF A0->GND cap (low ~2uA drain;
    cap compensates the high ADC source impedance) and documents the ratio for unequal resistors.
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2026-06-23 docs: recommend 55k:55k battery divider; 1M underreads on GPIO0 even with cap
    Measured on hardware: BAT+ 4.0V gave only 1.68V at D0 with a 1M:1M+100nF divider (should be
    2.0V) — the ADC pin's DC leakage loads a divider that high-impedance, and the cap only fixes AC
    settling. Use low-impedance resistors (55k:55k, ~27k Thevenin). DIV_X100 stays 200 (still ÷2).
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2026-06-24 Battery: make slave a real sleepy ED (rx_on_when_idle=false) + release RMT PM lock
    Follow-up to 1e67616. Diagnostics (esp_pm_dump_locks + CAN_SLEEP counters over
    serial) showed the slave was never sleeping despite esp_pm_configure: it had
    joined as a NON-sleepy end device (rx_on_when_idle=true), so the 802.15.4 radio
    stayed on continuously and the stack never raised CAN_SLEEP (counter stuck at 0).
    Two fixes:
    - espir_device: call esp_zb_set_rx_on_when_idle(false) for the slave before
    device register. esp_zb_sleep_enable() only enables the feature; the MAC
    capability must be set explicitly or the ED joins rx-on and never sleeps.
    (Existing slaves must re-commission once: their non-sleepy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
    [espir_device.c, espir_ir.c]
2026-06-24 slave-pcb: custom-PCB firmware with discrete IR driver + RGB status LED
    New `slave-pcb/` app target (mirrors `slave/`) for a purpose-built carrier PCB
    that reflows the XIAO ESP32-C6 as an SMD part, replaces the SZHJW module with a
    discrete low-side N-MOSFET IR driver on the same GPIO18, and adds a discrete RGB
    status LED:
    amber slow blink = searching for the network
    green solid = joined/connected (gated on USB power)
    blue rapid blink = sending an IR frame
    The solid green only lights while USB is present so a steady LED can't flatten
    the LiPo on a sleepy end device; the amber/blue blinks run on battery too (the
    CPU is already awake commissioning or sending). The LED task blocks w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
    [partitions.csv]
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2026-06-24 hardware: pin slave-pcb BOM to LCSC/JLCPCB part numbers
    Add confirmed LCSC part numbers to the custom-PCB BOM and wiring tables:
    AO3400A C20917, 2N7002 C8545, XIAO ESP32-C6 C9900124963, MX1.25 header
    ZX-MX1.25-2PWT C7430468. Passives flagged JLC Basic (match in the BOM tool).
    Status LED resolved to a real common-anode part: no common-anode XL-5050
    exists on LCSC, so use Everlight 22-23C/R6GHBHW-C01/2C (C181865). Its lower
    Vf (R 1.85 / G,B 2.9 V) and 5 mA rating change the ballasts to 470 ohm (red)
    and 220 ohm (green/blue), updated in both the table and the ASCII schematic.
    IR LED M3030E1IRS6G45-940 C# left as "confirm on LCSC" (not found by search).
    Live stock not verified here — confirm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
2026-06-25 oled: unwind I2C bus on init failure; guard fb_text against negative x
    [espir_oled.c]
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2026-06-28 master: dual-slot OTA partition table + app rollback
    [partitions.csv]
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2026-06-28 espir_ota: skip OTA sub-element header on first block (fixes broken update)
    The Zigbee OTA file format prepends a 6-byte sub-element header
    (tag u16 + length u32) before the ESP image data. The esp-zigbee stack
    strips only the 56-byte file header, so the first RECEIVE block began
    with those 6 bytes, placing the image magic 6 bytes into the partition
    and causing esp_ota_end() to reject every transfer.
    Add s_first_block flag: set on START, consumed on the first RECEIVE
    block by skipping the 6-byte sub-element header before writing.
    Matches the pattern used in the official esp-zigbee ota_client example.
    Also gate the OTA action-handler dispatch on s_cfg.ota for symmetry
    with cluster-registra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
    [espir_device.c]
2026-06-28 ota: add OTA to slave + slave-pcb (per-app image type 0x0002/0x0003)
    [partitions.csv]
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2026-06-30 hardware: add KiCad version of the slave PCB (circuit-as-code)
    Port the fully-custom slave board (originally EasyEDA Pro, not in git) to
    KiCad, fully in-repo and reproducible. Uses the ESP32-C6-MINI-1 module in
    place of the bare ESP32-C6 QFN-40, dropping the now-internal flash, crystal
    and antenna chain (WS2812 status LED remaps GPIO11 -> GPIO7).
    Pipeline (build.sh): SKiDL circuit-as-code -> netlist + ERC -> make_schematic
    (connect-by-name .kicad_sch) and kinet2pcb -> .kicad_pcb -> pcbnew functional
    placement + board outline. Verified: SKiDL ERC 0 errors; KiCad re-extracts the
    exact 25-net netlist from the schematic; DRC clean except the unrouted ratsnest.
    Adds espir_slave_pcb.kicad_dru wi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
    [espir_slave_pcb.kicad_pcb, espir_slave_pcb.kicad_sch]
2026-06-30 hardware: autoroute the KiCad slave PCB (Freerouting)
    Add net classes (Power 0.5mm, IR 0.4mm) in place_and_outline.py so the
    current-carrying rails route wide, then autoroute headless via Freerouting
    (route.sh: pcbnew ExportSpecctraDSN -> freerouting -> ImportSpecctraSES).
    ~90% routed (310 tracks, 26 vias): 104 of 114 connections. Carrying the net
    classes into the DSN cut track_width DRC violations from 199 (uniform width)
    to 8. The last 10 (IR-LED corner + WS2812 group) are too cramped to reach on
    2 layers and, with the antenna-keepout / edge-clearance cleanup, are the GUI
    finishing pass (4 layers would let it fully autoroute).
    [espir_slave_pcb.kicad_pcb]
2026-06-30 hardware: fix module placement (antenna keep-out off-board) + centre on sheet
    The ESP32-C6-MINI-1 footprint embeds a (keepout (tracks not_allowed)) antenna
    zone (x±21.6, y[-26,-5.6]mm from origin). With the module in the board interior
    that no-tracks band covered the IR LEDs (U2/U3) and WS2812 (LED1), making them
    un-routable. Move the module so its body sits at the top edge and the antenna +
    keep-out hang OFF the board: 19 keep-out DRC violations -> 0 and those nets now
    route. Re-route lifts coverage ~90% -> ~98% (2 unrouted, 355 tracks, 25 vias).
    Also offset placement + outline so the board is centred on the A4 sheet
    (148.5, 105mm) instead of in the top-left corner. Previews regenerated.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
    [espir_slave_pcb.kicad_pcb]
2026-06-30 hardware: DRC fixes — fully routed, wide power, clean except benign edge silk
    Take DRC from 27 violations + 2 unrouted to 4 (all benign):
    - Re-route to 0 unrouted (114/114; 540 tracks, 27 vias).
    - Grow the right edge 1.5mm so SW1/SW2 pads + tracks clear it (8 copper_edge
    clearance -> 0).
    - Main power rails widened to 0.5mm (track_width -> 0); VBAT kept at default in
    the congested charger corner (2-layer can't widen it there without clearance
    violations) — .kicad_dru updated to a VBAT-specific 0.2mm rule, rest 0.5mm.
    - Delete zero-length track artifacts from the SES import.
    - Silkscreen: collision-aware reposition of overlapping designators; hide LED2/
    USBC1 refs in the saturated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
    [espir_slave_pcb.kicad_pcb]
2026-06-30 hardware: convert slave PCB to 4-layer, wide VBAT, GND planes
    Per request — minimal cost delta, don't sacrifice stability:
    - 4 copper layers (F/In1/In2/B) via place_and_outline; GND pours on all four
    layers + collision-checked stitching-via grid (pour_gnd.py) → inner ground
    reference planes.
    - The extra routing room lets every Power-class rail, including VBAT, route at
    0.5 mm (dropped the 2-layer VBAT 0.2 mm compromise; .kicad_dru back to 0.5).
    - Fully routed 114/114 (310 tracks, 43 vias). LDO EN (tied to VSYS, boxed by
    U6's VIN/GND pins) jumpered VIN→EN on B.Cu under the GND pin.
    - Grew board to 54 mm wide so the edge buttons clear the edge without colliding
    with the strap r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
    [espir_slave_pcb.kicad_pcb]
2026-06-30 hardware: enforce edge clearance for passives in the placement pipeline
    Address components sitting too close to the board edge:
    - place_and_outline.py: enforce >=1mm board-edge clearance for every
    non-port/antenna part (push inward if a courtyard is too close); move the
    USB-C CC pulldowns (R11/R12) right above the connector's CC pads so the CC
    nets route trivially; move D1 off the USB-C CC pads; charger cluster off the
    bottom edge.
    - pour_gnd.py: solid (FULL) GND-pad zone connection -> no starved-thermal.
    - en_jumper.py: script the LDO EN->VIN B.Cu jumper (boxed SOT-23-5 pins
    Freerouting can't tie).
    The committed .kicad_pcb stays the verified-clean board (LED2/R14 ~0.8mm from
    the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
    [place_and_outline.py, pour_gnd.py]
2026-06-30 hardware: round corners + 4x M3 mounting holes (expand board on X)
    mounting_and_round.py (runs on the routed board — no re-route needed):
    - expand the board on X to 66mm (symmetric, stays centred) so the packed
    components get clear left/right margins;
    - round all four corners (r=3mm);
    - add 4x M3 mounting holes (3.2mm Edge.Cuts cutouts) in the new margins, clear
    of every component — the GND pour isolates them with a ring.
    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
    [espir_slave_pcb.kicad_pcb]
2026-06-30 hardware: change RESET/BOOT buttons from THT 6mm to SMD tactile (KMR2)
    Swap SW1/SW2 from Button_Switch_THT:SW_PUSH_6mm to
    Button_Switch_SMD:SW_Push_1P1T_NO_CK_KMR2, in both the SKiDL source and the
    routed board (swap_smd_button.py, run per-button in its own process to dodge
    pcbnew SWIG state corruption):
    - assign the new pads' nets AFTER Add (Add clears nets set beforehand);
    - bridge the EN/BOOT signal once per old pad position to the nearest new pad;
    - add a via at each old (through-hole) pad position so the inner/bottom-layer
    tracks that connected through the THT hole stay on-net;
    - drop the dangling GND stubs — the 4-layer GND pour reconnects the new GND pads.
    DRC: 0 unconnected, 0 e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
    [espir_slave_pcb.kicad_pcb]
2026-06-30 hardware: re-solve routing after U7 (JST battery connector) move
    U7 was moved + rotated -90° in the GUI, which broke local routing:
    - VCELL (U7.1 -> SW3.3) left dangling in two pieces -> cleared the fragments
    and re-routed it on F.Cu (right, then down, clear of U7's own GND pad), 0.5mm
    Power class;
    - U7's mounting pads landed on two GND stitch vias (short + hole-clearance +
    mask-bridge) -> removed those two vias (the pour still grounds the area);
    - trimmed a stray dangling V3V3 stub.
    Re-poured all four GND layers.
    DRC: 0 unconnected, 0 electrical violations (only the 4 benign edge-silk + 1
    benign lib_footprint_mismatch).
    [espir_slave_pcb.kicad_pcb]
2026-06-30 hardware: pour GND planes before routing (no redundant GND traces)
    Root cause of the redundant GND traces: the pipeline routed first, so
    Freerouting filled GND with traces (119 here) that the pour then made
    pointless. A filled GND zone exports to the Specctra DSN as (plane GND ...)
    per layer, so pouring the planes BEFORE routing makes Freerouting treat GND as
    already-connected and route only the signal nets (adding just the pad-to-plane
    vias GND needs).
    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
    [espir_slave_pcb.kicad_pcb]
2026-07-01 slave-pcb: green LED as 3s join pulse, drop USB gating
    The solid-green CONNECTED indicator was gated on a VBUS-sense GPIO so it
    wouldn't drain the LiPo on battery. On the sleepy end device that never
    worked: once automatic light sleep engaged (~5s after joining), ESP-IDF's
    GPIO reset workaround perturbed the high-impedance VBUS divider node and
    the read latched green on regardless of USB.
    Replace the USB gating with a power-source-independent behaviour: green is
    a one-shot 3s "joined" confirmation, then dark. The pulse fires only on the
    join transition (SEARCHING -> CONNECTED), not after IR sends
    (SENDING -> CONNECTED goes straight dark). espir_led_set() is now
    idempotent so a duplicate CON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
    [espir_led.c, espir_led.h, main.c]
2026-07-01 docs: note the sleepy-ED flash wake-window trick for both slave PCBs
    The C6 slave boards expose only native USB-Serial-JTAG and light-sleep as
    Zigbee sleepy end devices, so idf.py flash fails with Errno 71 unless an
    attempt lands in the brief post-reset window. Document the retry-loop
    method (and BOOT+RESET download mode) in both slave-PCB references.
